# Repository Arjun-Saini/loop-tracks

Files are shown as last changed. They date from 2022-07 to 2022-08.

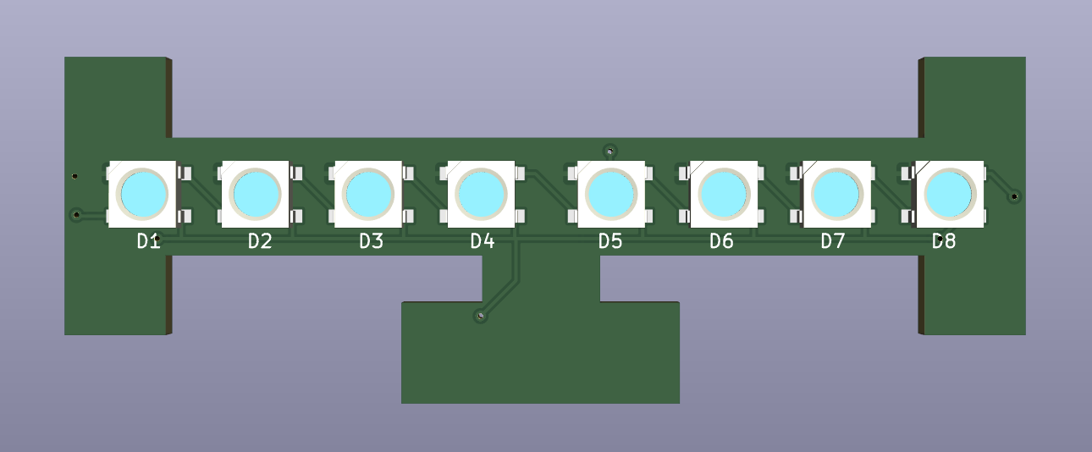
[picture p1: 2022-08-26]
images and diagrams/offshoot right.png

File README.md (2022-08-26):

# loop-tracks

This is the main repository for the loop-tracks project.
The server and UI for this project can be found at [loop-tracks-server](https://github.com/cogsandsquigs/loop-tracks-server) and [loop-tracks-ui](https://github.com/cogsandsquigs/loop-tracks-ui). Full documentation and other information for the project located [here](https://arjun-saini.notion.site/arjun-saini/Loop-Tracks-0d7150e50bd84f2c9db64b674ca986d8).

## images and diagrams

Images and diagrams used in the notion page.

## PCB Design

PCB project files for each track component, designed with [KiCad 6](https://www.kicad.org/).

## master

Master I2C device, code written for a [Particle Argon](https://docs.particle.io/argon/) using DeviceOS 5.0.0.

## slave

Slave I2C devices, code written for an [ATmega328p](https://www.microchip.com/en-us/product/ATmega328).

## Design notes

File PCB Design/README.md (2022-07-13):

# loop-tracks PCB designs
These are the PCB designs for the loop-tracks project

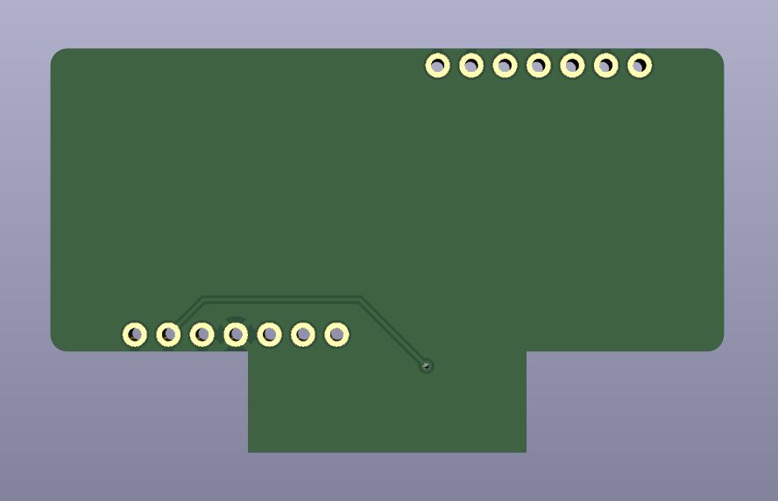
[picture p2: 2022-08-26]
images and diagrams/14-seg display.png

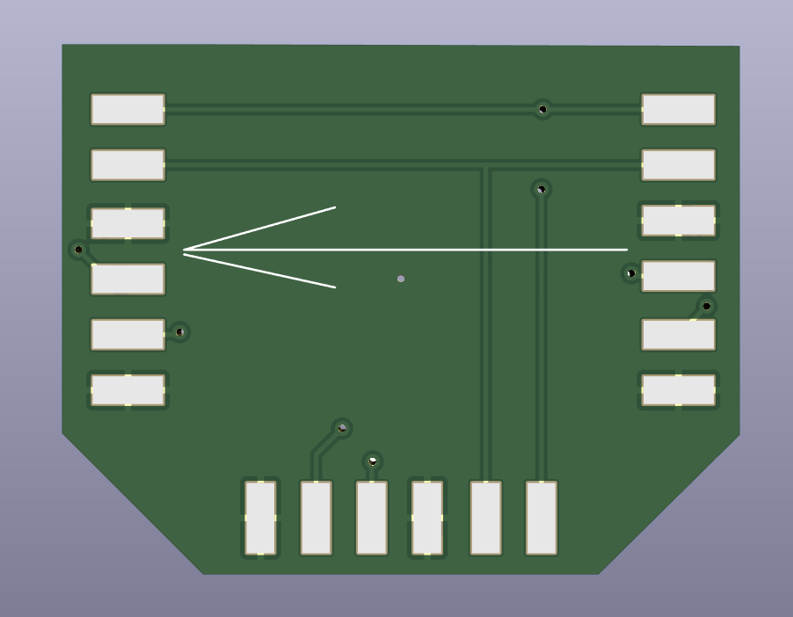
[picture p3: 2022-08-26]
images and diagrams/straight right arrows.png

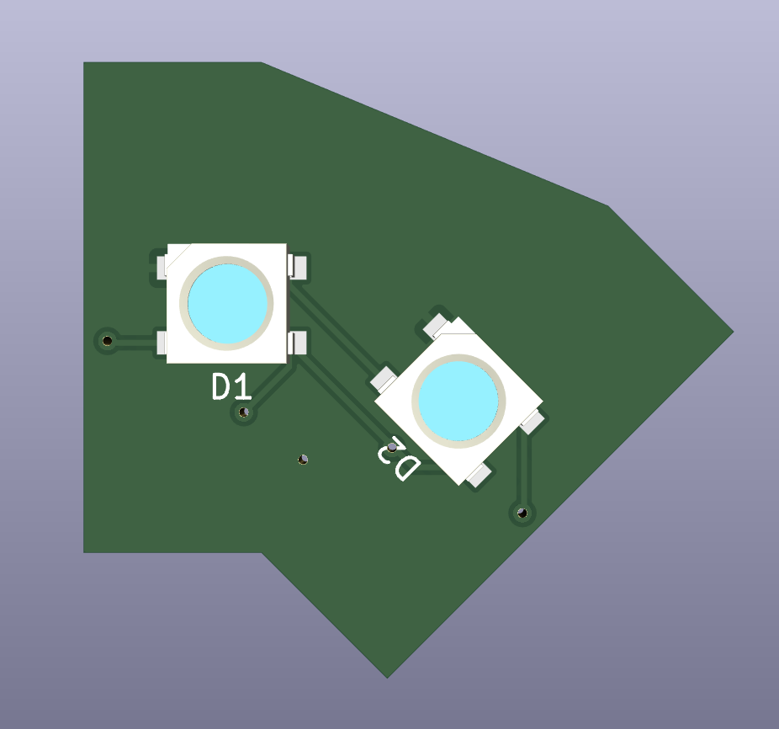
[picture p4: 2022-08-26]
images and diagrams/45 right.png

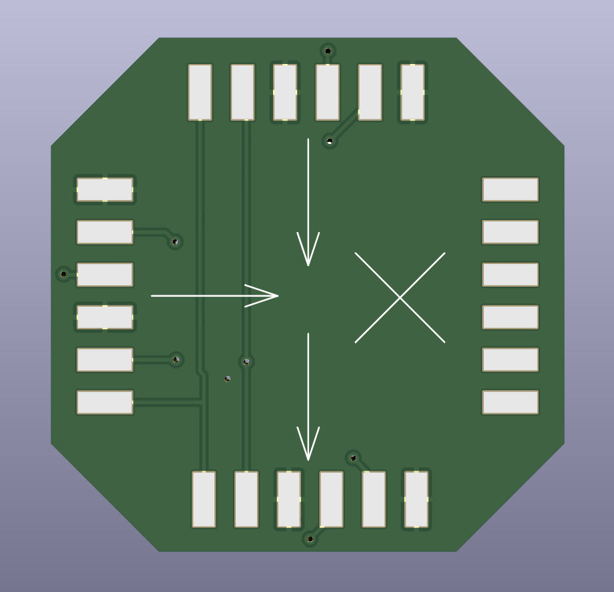
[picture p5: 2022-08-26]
images and diagrams/blocked intersection arrows.png

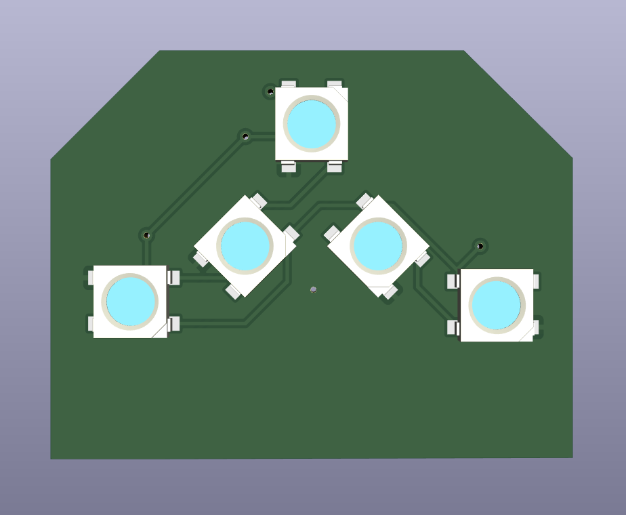
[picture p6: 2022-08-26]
images and diagrams/T-intersection.png

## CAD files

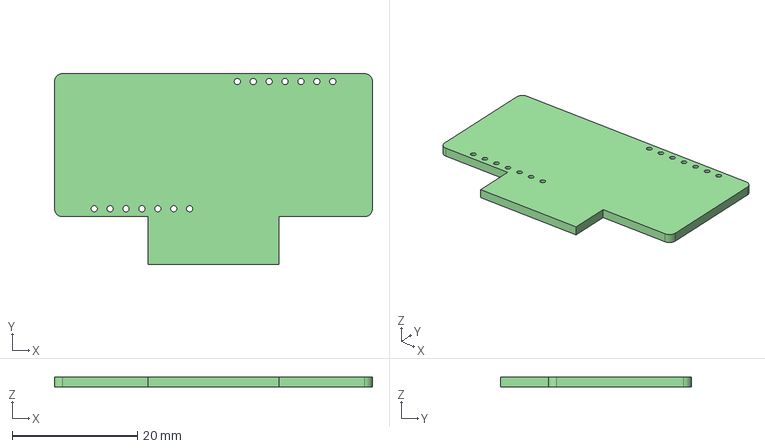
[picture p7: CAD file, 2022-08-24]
PCB Design/3d models/14 segment display.STEP
50.8 x 30.5 x 1.60 mm

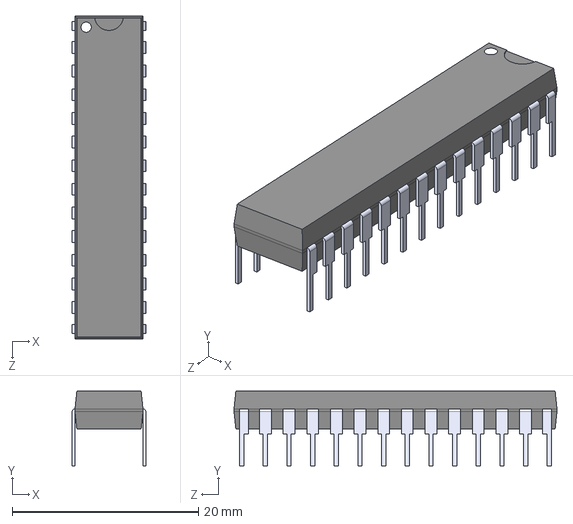
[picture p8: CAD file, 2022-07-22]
PCB Design/microcontroller_th/ATMEGA328P-PU/ATMEGA328P-PU.step
7.90 x 8.00 x 34.7 mm

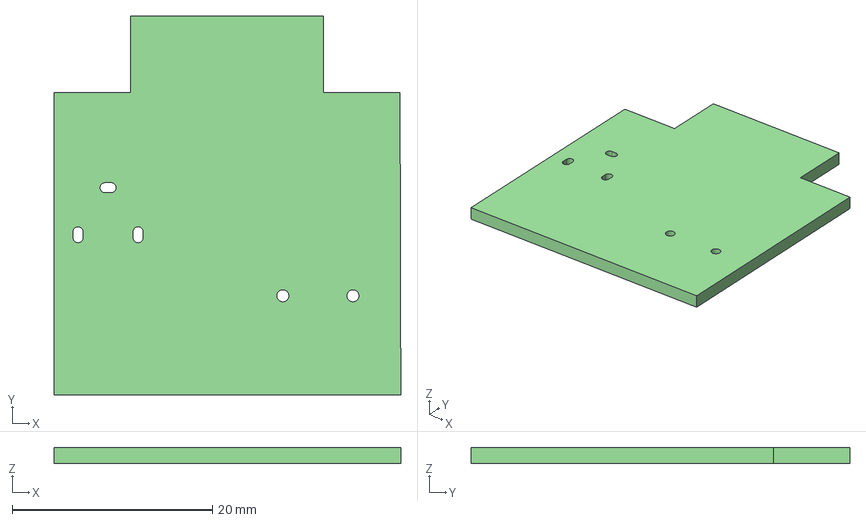
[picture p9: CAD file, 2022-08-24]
PCB Design/3d models/power mount.STEP
34.6 x 37.8 x 1.60 mm

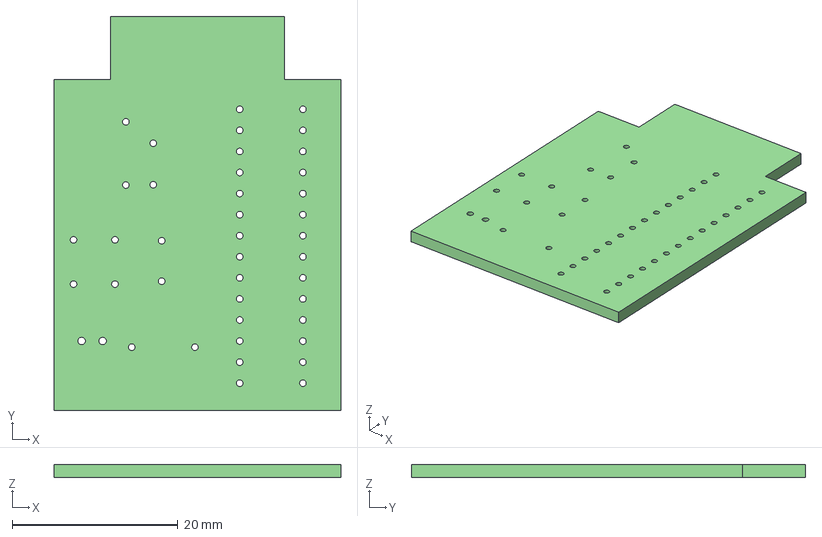
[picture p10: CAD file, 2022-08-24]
PCB Design/3d models/microcontroller mount.STEP
34.5 x 47.5 x 1.60 mm

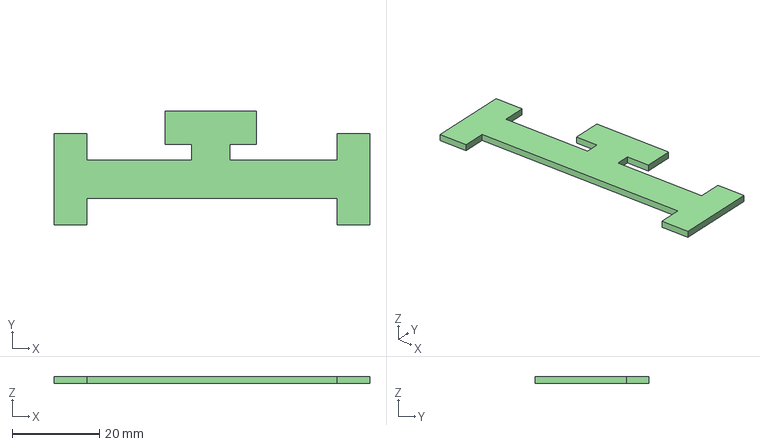
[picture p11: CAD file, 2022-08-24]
PCB Design/3d models/straight stick offshoot.STEP
72.5 x 26.1 x 1.60 mm

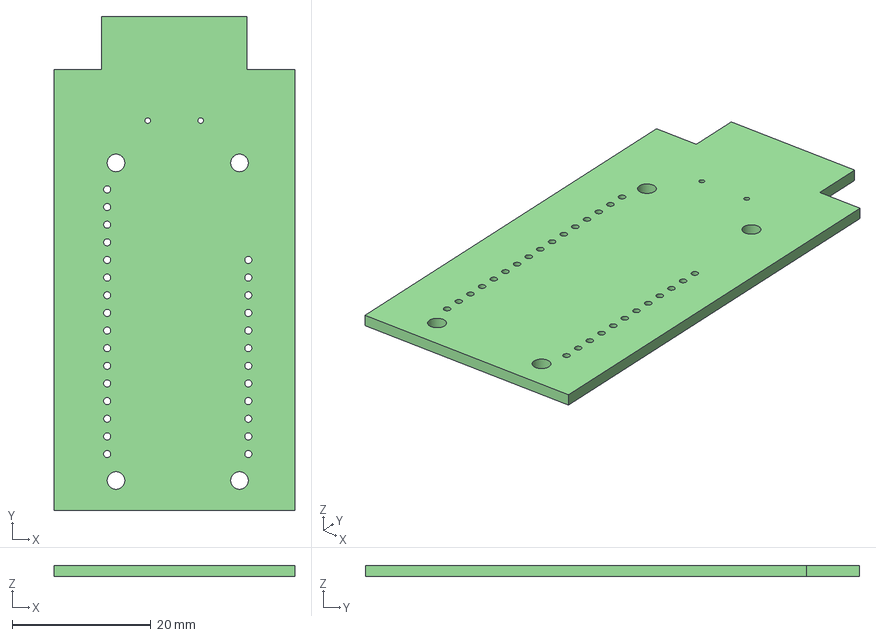
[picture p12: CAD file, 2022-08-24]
PCB Design/3d models/argon mount.STEP
34.6 x 71.1 x 1.60 mm

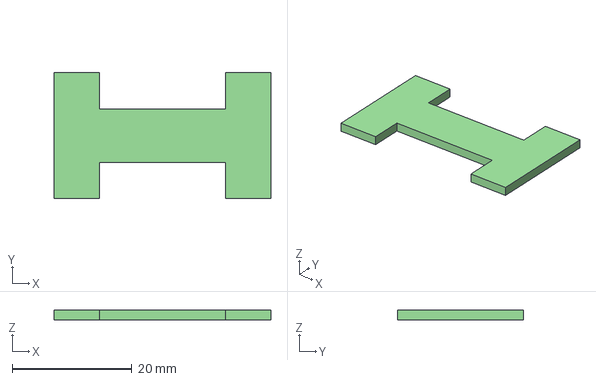
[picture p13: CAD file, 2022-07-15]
PCB Design/3d models/straight stick half size.STEP
36.2 x 21.0 x 1.60 mm

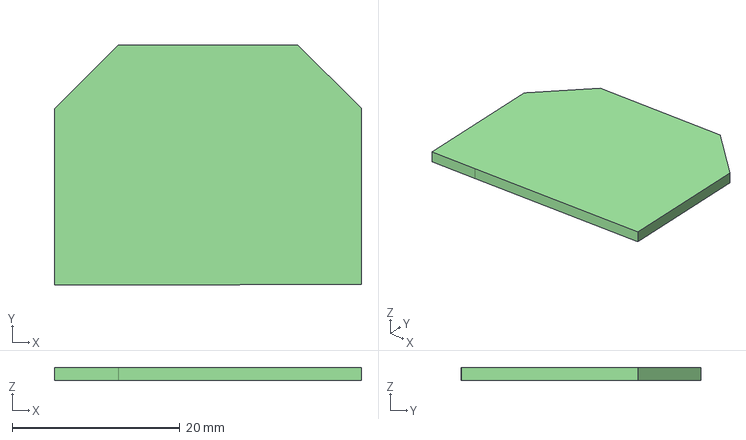
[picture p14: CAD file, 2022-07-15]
PCB Design/3d models/T straight right.STEP
36.6 x 28.6 x 1.60 mm

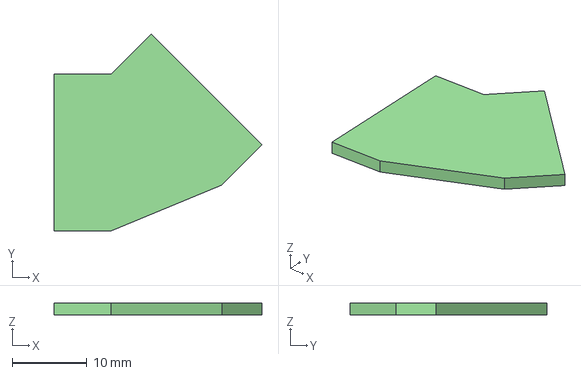
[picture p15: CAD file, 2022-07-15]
PCB Design/3d models/45 degree left.STEP
27.9 x 26.4 x 1.60 mm

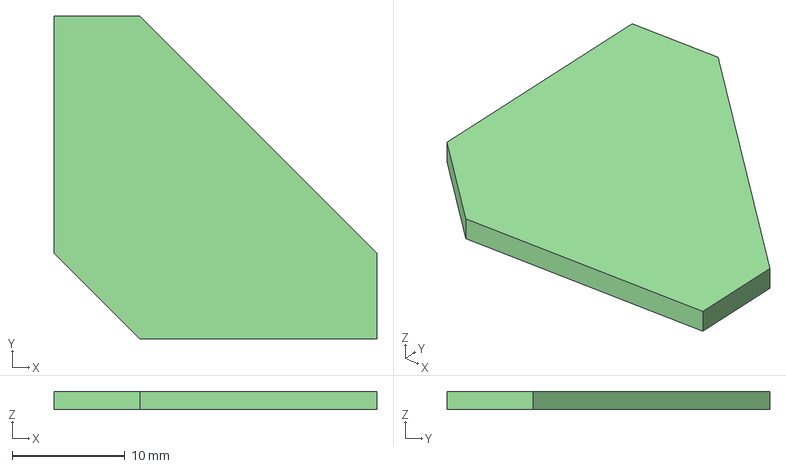
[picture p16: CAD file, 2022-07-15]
PCB Design/3d models/90 degree right.STEP
28.6 x 28.6 x 1.60 mm

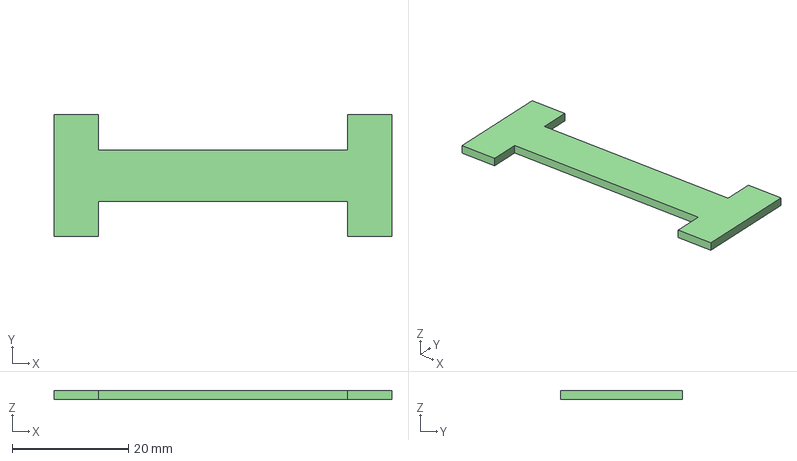
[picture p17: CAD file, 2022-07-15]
PCB Design/3d models/straight stick.STEP
58.2 x 21.0 x 1.60 mm

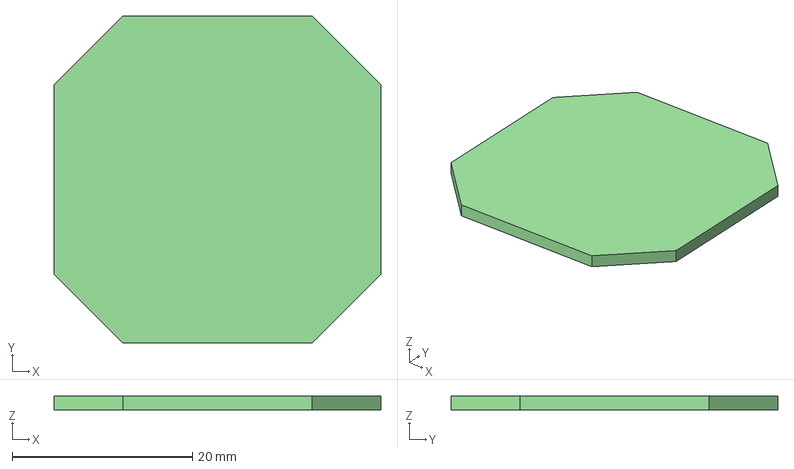
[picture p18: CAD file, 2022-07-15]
PCB Design/3d models/intersection.STEP
36.2 x 36.2 x 1.60 mm

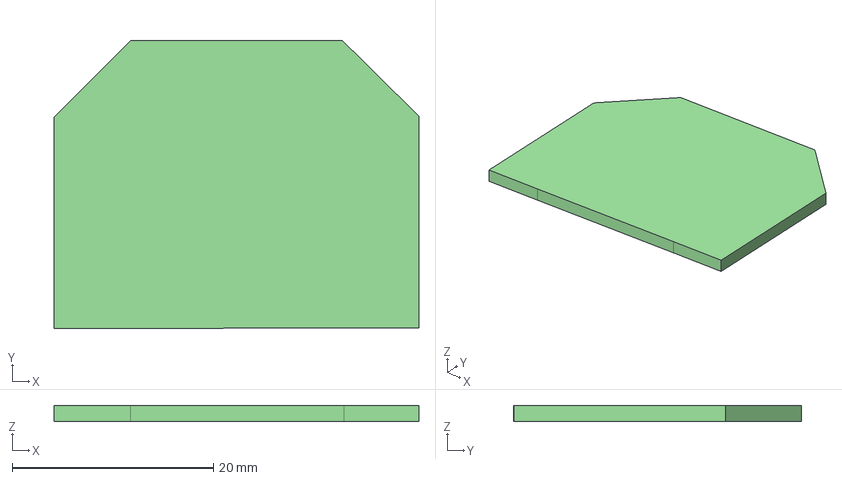
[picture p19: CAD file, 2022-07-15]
PCB Design/3d models/T turn from left.STEP
36.2 x 28.6 x 1.60 mm

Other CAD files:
PCB Design/3d models/T straight left.STEP
PCB Design/3d models/45 degree right.STEP
PCB Design/3d models/90 degree left.STEP
PCB Design/3d models/T turn from right.STEP

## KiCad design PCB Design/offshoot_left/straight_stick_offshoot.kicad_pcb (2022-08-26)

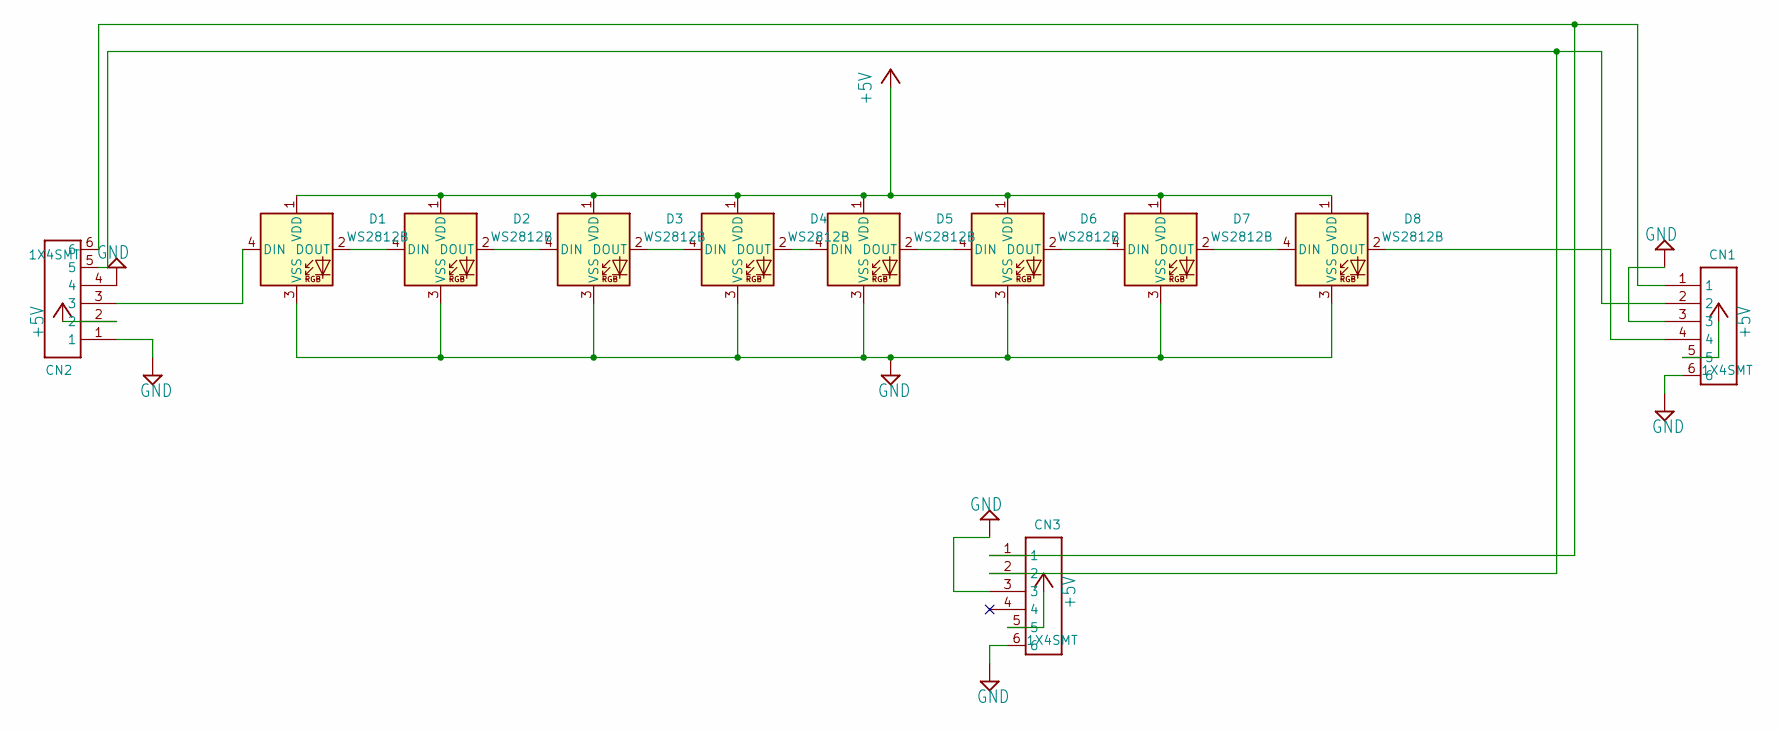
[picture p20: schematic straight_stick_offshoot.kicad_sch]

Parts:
CN1, CN2, CN3: 1X4SMT; 1X4-SMT
D1, D2, D3, D4, D5, D6, D7, D8: WS2812B; LED_WS2812B_PLCC4_5.0x5.0mm_P3.2mm

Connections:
+5V: CN1.5, CN2.2, CN3.5, D1.1 (VDD), D2.1 (VDD), D3.1 (VDD), D4.1 (VDD), D5.1 (VDD), D6.1 (VDD), D7.1 (VDD), D8.1 (VDD)
GND: CN1.3, CN1.6, CN2.1, CN2.4, CN3.3, CN3.6, D1.3 (VSS), D2.3 (VSS), D3.3 (VSS), D4.3 (VSS), D5.3 (VSS), D6.3 (VSS), D7.3 (VSS), D8.3 (VSS)
unnamed: CN1.1, CN2.6, CN3.1
unnamed: CN1.2, CN2.5, CN3.2
unnamed: CN1.4, D8.2 (DOUT)
unnamed: CN2.3, D1.4 (DIN)
unnamed: D1.2 (DOUT), D2.4 (DIN)
unnamed: D2.2 (DOUT), D3.4 (DIN)
unnamed: D3.2 (DOUT), D4.4 (DIN)
unnamed: D4.2 (DOUT), D5.4 (DIN)
unnamed: D5.2 (DOUT), D6.4 (DIN)
unnamed: D6.2 (DOUT), D7.4 (DIN)
unnamed: D7.2 (DOUT), D8.4 (DIN)

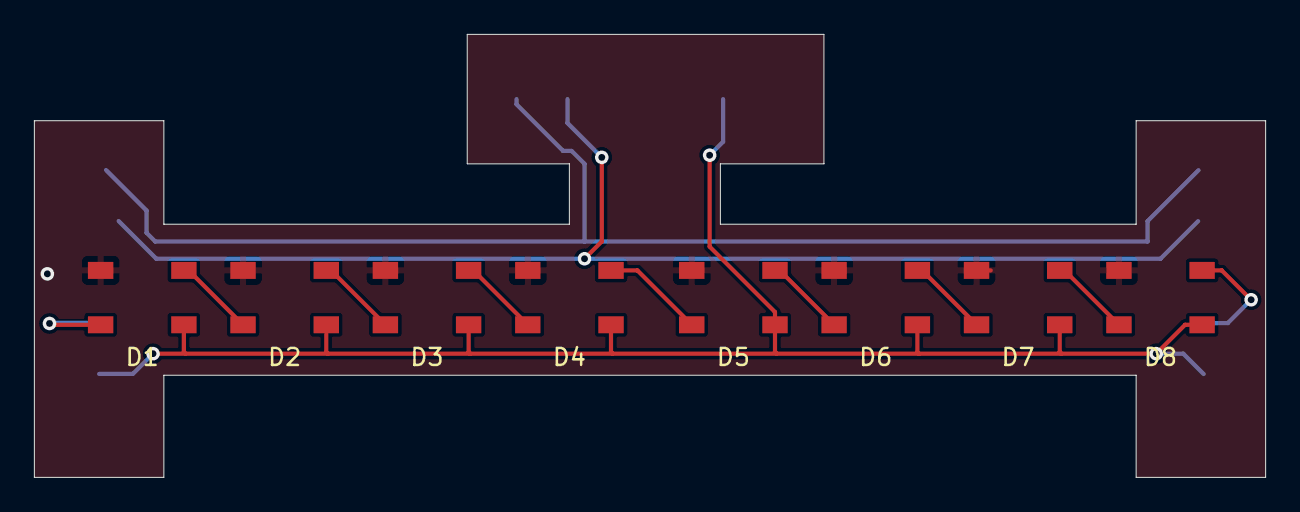
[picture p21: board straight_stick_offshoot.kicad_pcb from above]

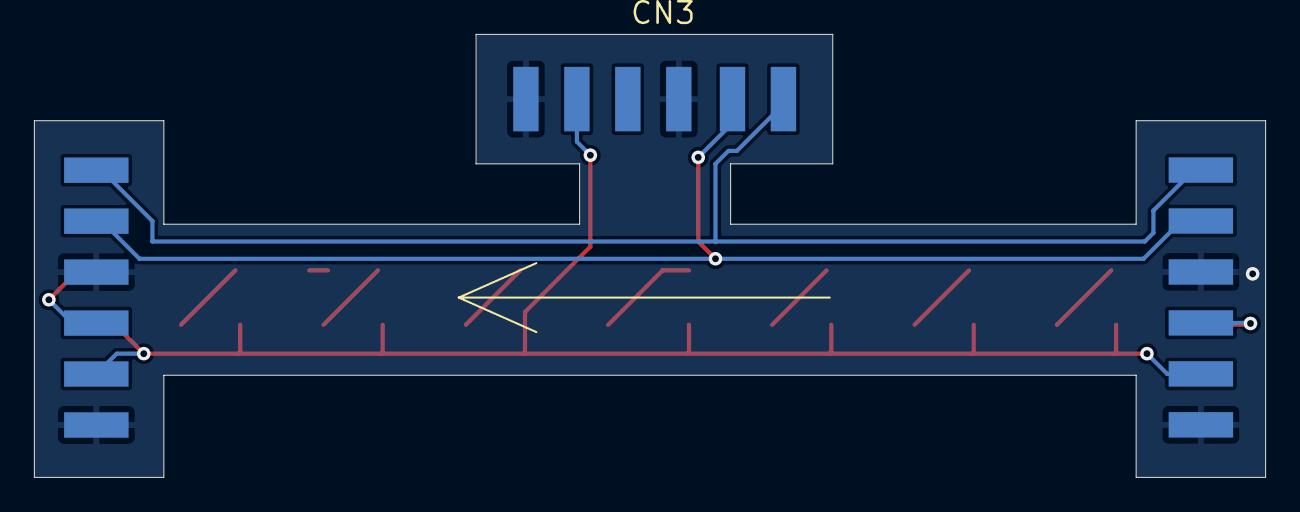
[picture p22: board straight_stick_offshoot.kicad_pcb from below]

Board: 2 copper layers, 72.5 x 26.1 mm, 11 parts (3 on the bottom side), 13 nets.

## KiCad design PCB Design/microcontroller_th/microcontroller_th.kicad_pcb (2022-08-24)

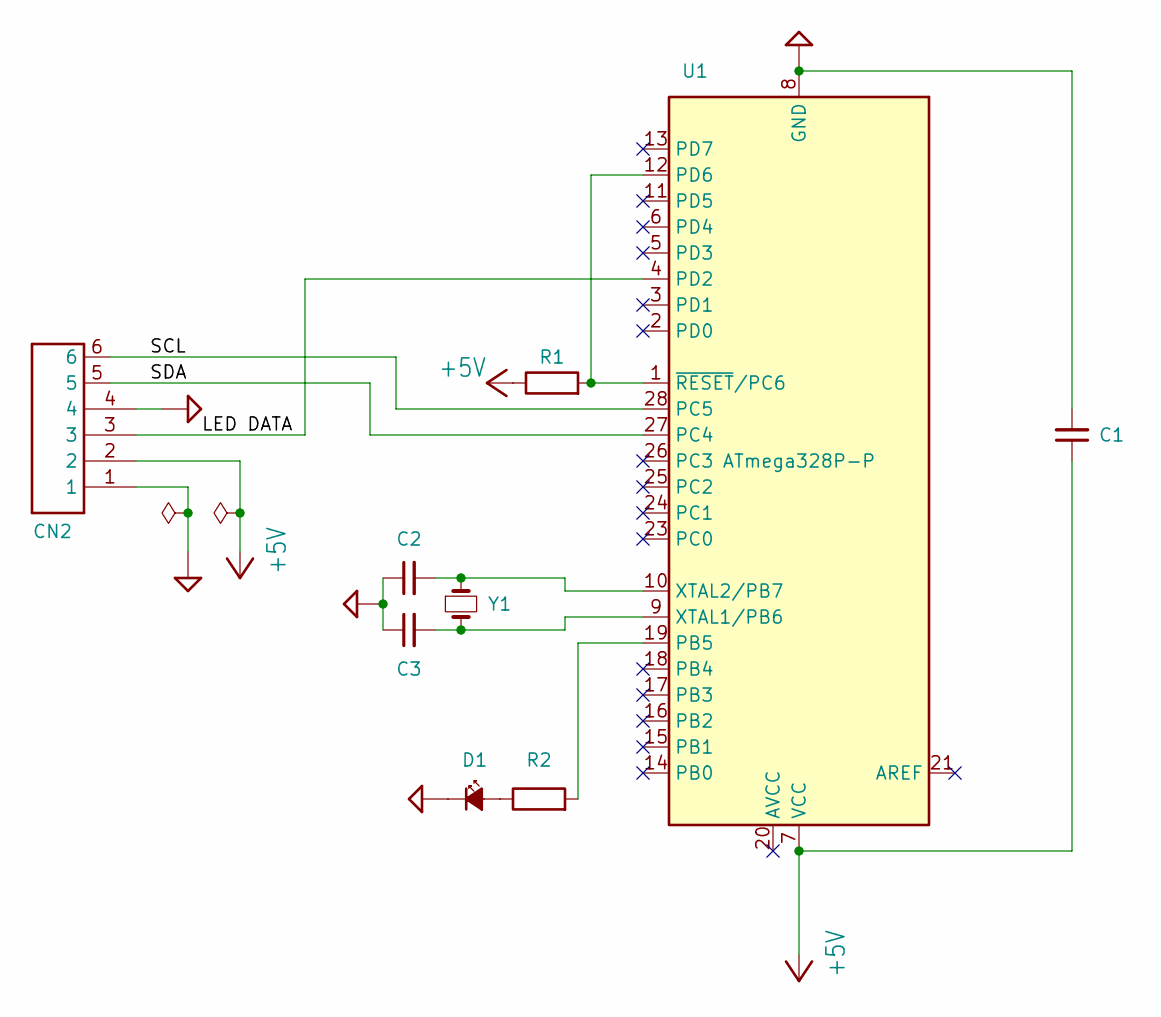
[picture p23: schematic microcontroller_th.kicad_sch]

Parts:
C1, C2, C3: C_Small; C_Disc_D4.7mm_W2.5mm_P5.00mm
CN2: 1X4SMT; 1X4-SMT
D1: LED_Small_Filled; LED_D3.0mm
R1, R2: R; R_Axial_DIN0207_L6.3mm_D2.5mm_P7.62mm_Horizontal
U1: ATmega328P-P; DIP-28_W7.62mm
Y1: Crystal_Small; Crystal_HC49-U_Vertical

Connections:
+5V: C1.1, CN2.2, R1.1, U1.7 (VCC)
/LED DATA: CN2.3, U1.4 (PD2)
/SCL: CN2.6, U1.28 (PC5)
/SDA: CN2.5, U1.27 (PC4)
GND: C1.2, C2.1, C3.1, CN2.1, CN2.4, D1.1 (K), U1.8 (GND), U1.22 (GND)
unnamed: C2.2, U1.10 (XTAL2/PB7), Y1.1
unnamed: C3.2, U1.9 (XTAL1/PB6), Y1.2
unnamed: D1.2 (A), R2.1
unnamed: R2.2, U1.19 (PB5)
unnamed: R1.2, U1.1 (~RESET/PC6), U1.12 (PD6)

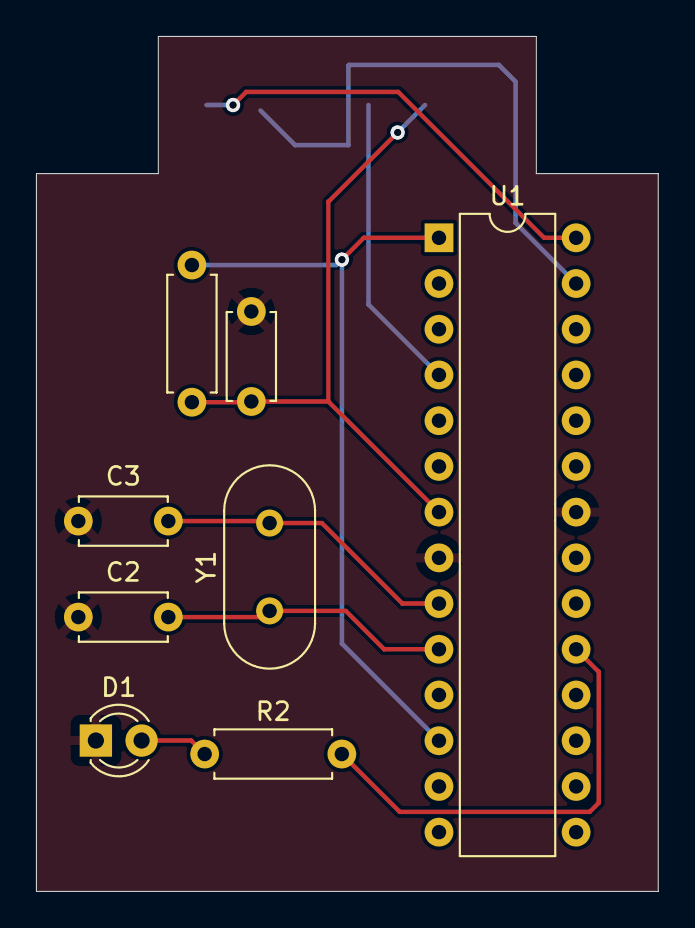
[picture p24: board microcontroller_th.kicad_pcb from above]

Board: 2 copper layers, 34.5 x 47.5 mm, 9 parts (1 on the bottom side), 10 nets.

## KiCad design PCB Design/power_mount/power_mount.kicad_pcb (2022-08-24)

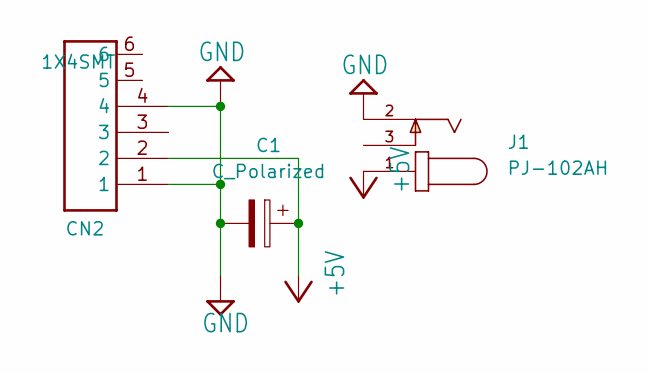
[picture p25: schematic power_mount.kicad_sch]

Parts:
C1: C_Polarized; CP_Radial_D12.5mm_P6.00mm
CN2: 1X4SMT; 1X4-SMT
J1: PJ-102AH

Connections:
+5V: C1.1, CN2.2, J1.1
GND: C1.2, CN2.1, CN2.4, J1.2

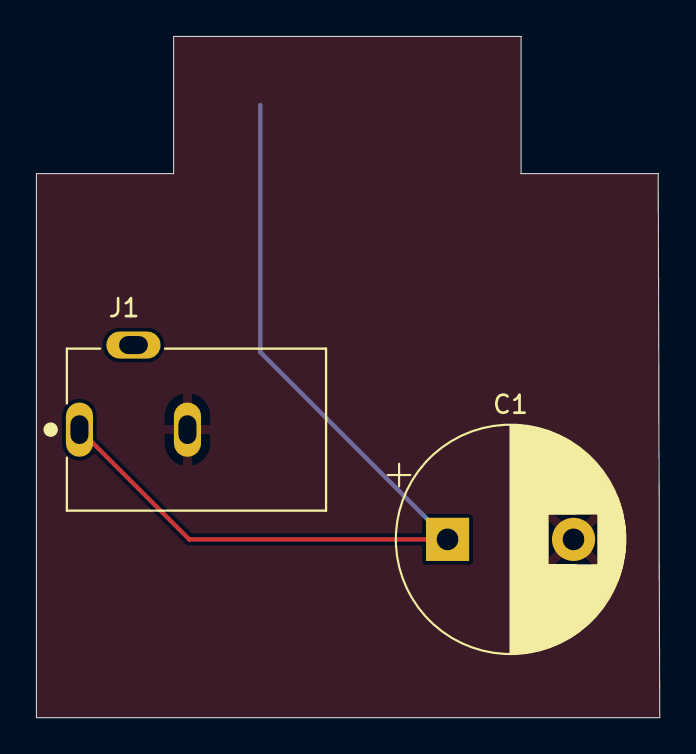
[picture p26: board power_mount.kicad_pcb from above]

Board: 2 copper layers, 34.6 x 37.8 mm, 3 parts (1 on the bottom side), 2 nets.

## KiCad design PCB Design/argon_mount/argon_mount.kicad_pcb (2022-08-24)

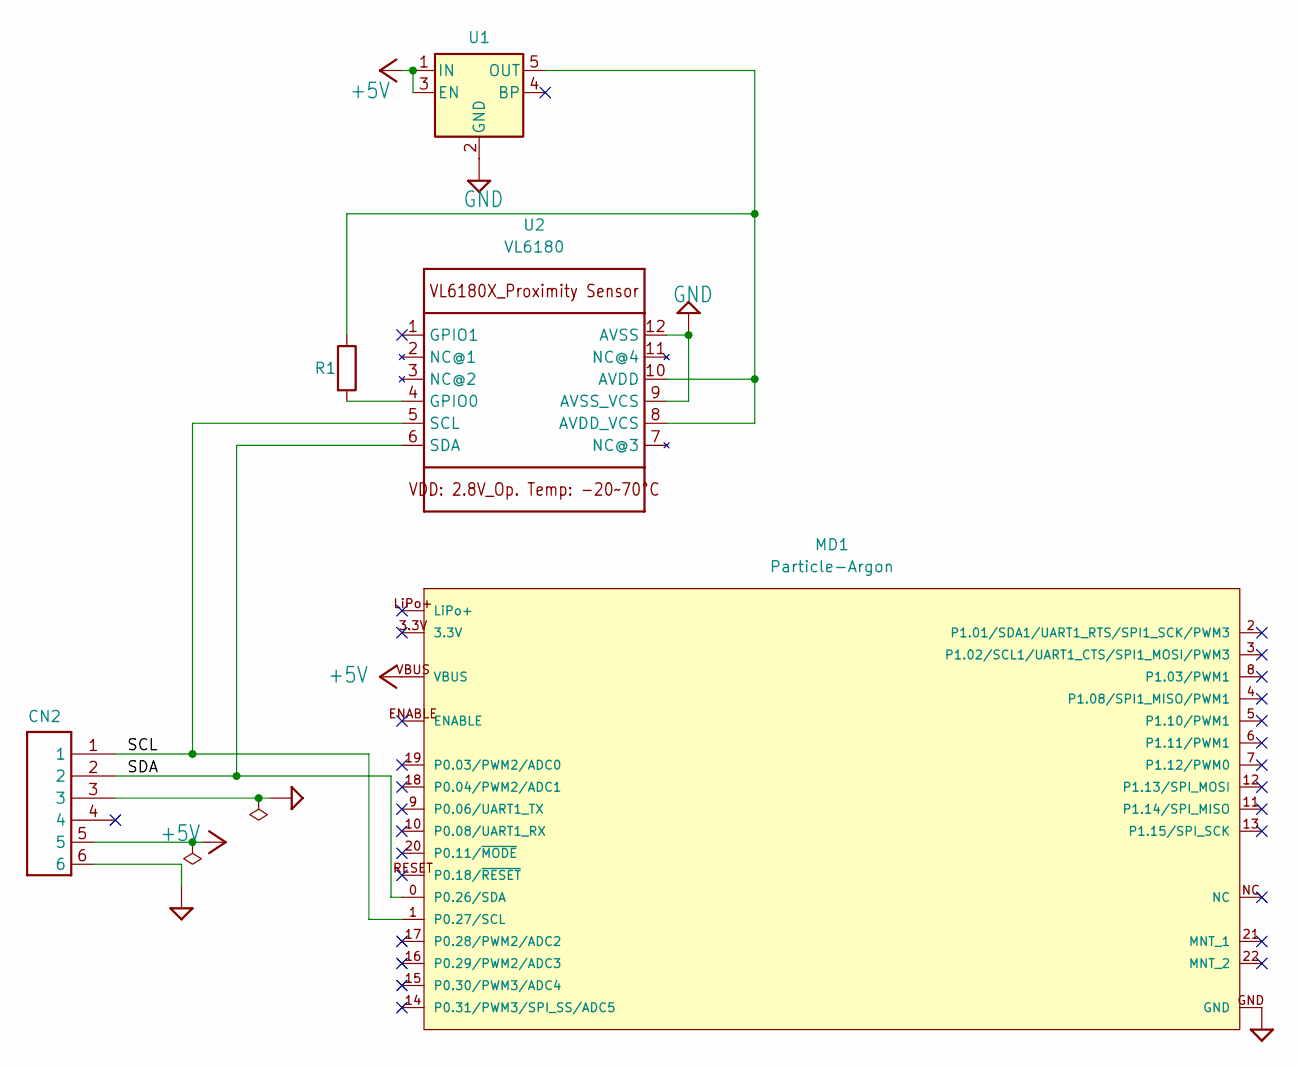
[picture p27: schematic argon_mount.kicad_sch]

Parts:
CN2: 1X4SMT; 1X4-SMT
MD1: Particle-Argon; Particle-Argon-0-0-MD1; manufacturer Particle; digikey description Bluetooth, WiFi 802.11b/g/n, Bluetooth 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
R1: R; R_Axial_DIN0207_L6.3mm_D2.5mm_P7.62mm_Horizontal
U1: MIC5219-2.85YM5; SOT-23-5
U2: VL6180

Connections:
+5V: CN2.5, MD1.VBUS, U1.1 (IN), U1.3 (EN)
/SCL: CN2.1, MD1.1 (P0.27/SCL), U2.5 (SCL)
/SDA: CN2.2, MD1.0 (P0.26/SDA), U2.6 (SDA)
GND: CN2.3, CN2.6, MD1.GND, U1.2 (GND), U2.9 (AVSS_VCS), U2.12 (AVSS)
unnamed: R1.1, U1.5 (OUT), U2.8 (AVDD_VCS), U2.10 (AVDD)
unnamed: R1.2, U2.4 (GPIO0)

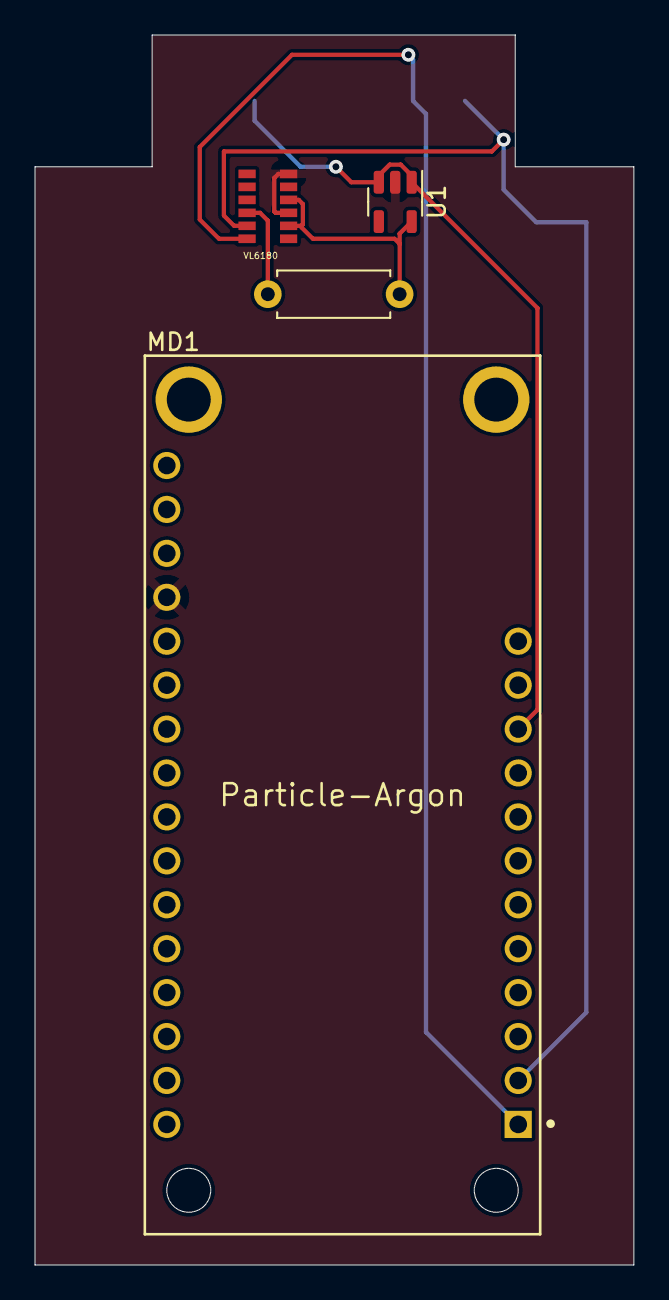
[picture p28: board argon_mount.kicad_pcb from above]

Board: 2 copper layers, 34.6 x 71.1 mm, 5 parts (1 on the bottom side), 6 nets.

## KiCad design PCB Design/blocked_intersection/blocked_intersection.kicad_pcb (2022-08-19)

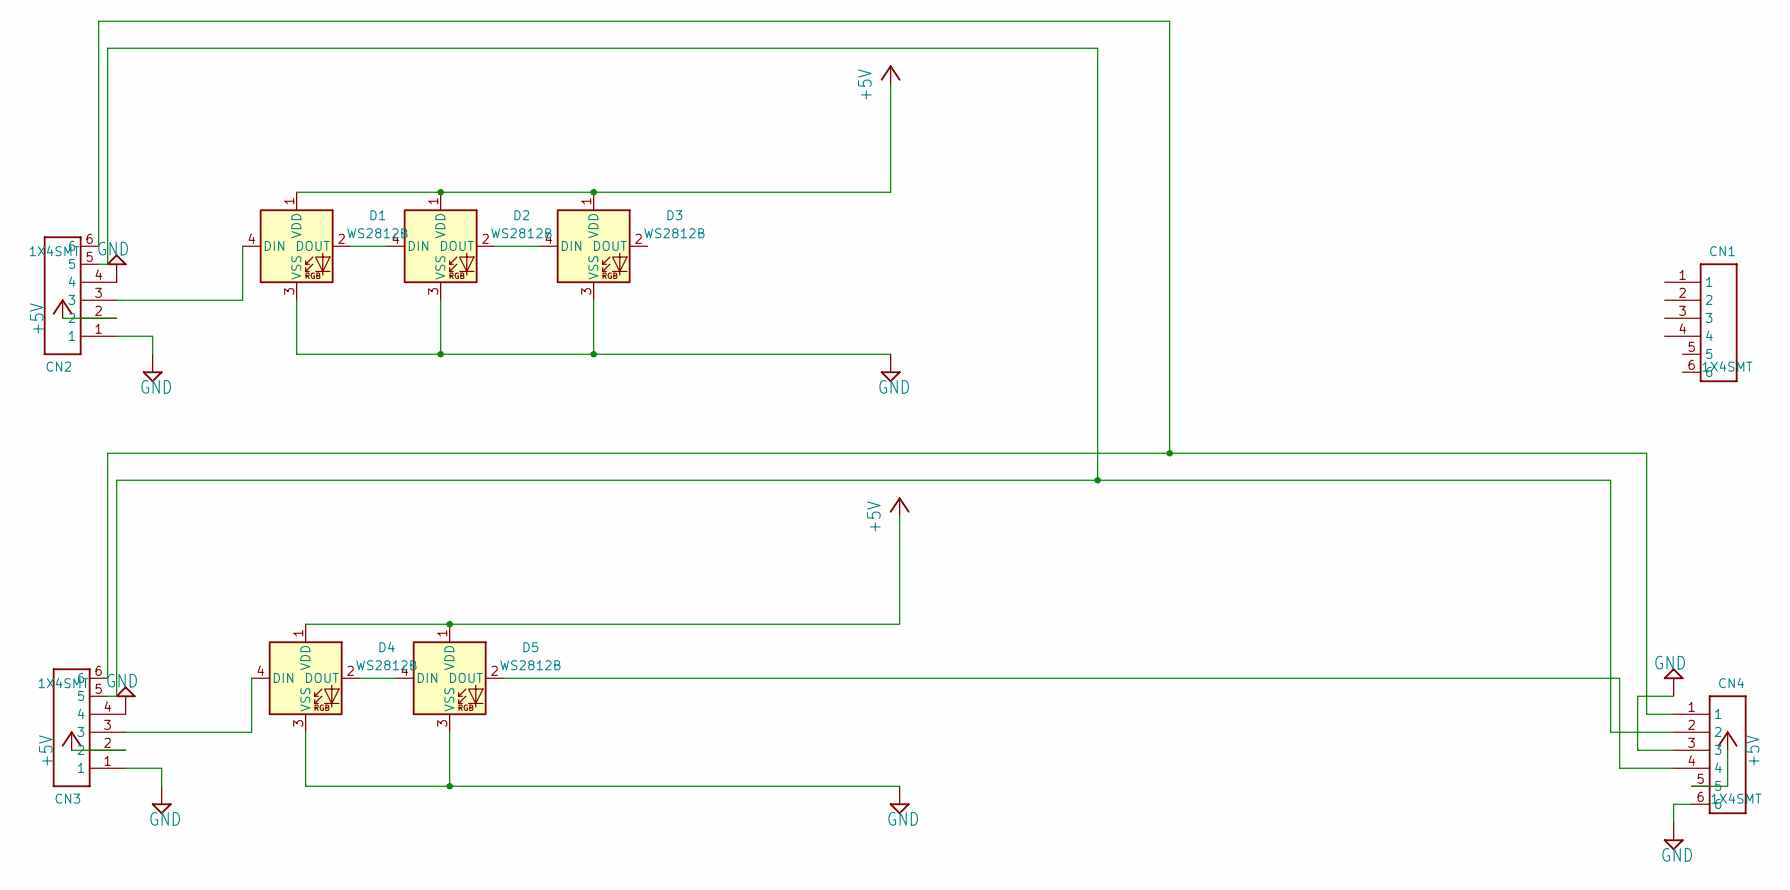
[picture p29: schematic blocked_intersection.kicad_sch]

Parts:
CN1, CN2, CN3, CN4: 1X4SMT; 1X4-SMT
D1, D2, D3, D4, D5: WS2812B; LED_WS2812B_PLCC4_5.0x5.0mm_P3.2mm

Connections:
+5V: CN2.2, CN3.2, CN4.5, D1.1 (VDD), D2.1 (VDD), D3.1 (VDD), D4.1 (VDD), D5.1 (VDD)
GND: CN2.1, CN2.4, CN3.1, CN3.4, CN4.3, CN4.6, D1.3 (VSS), D2.3 (VSS), D3.3 (VSS), D4.3 (VSS), D5.3 (VSS)
unnamed: CN2.3, D1.4 (DIN)
unnamed: CN2.5, CN3.5, CN4.2
unnamed: CN2.6, CN3.6, CN4.1
unnamed: CN3.3, D4.4 (DIN)
unnamed: D1.2 (DOUT), D2.4 (DIN)
unnamed: D2.2 (DOUT), D3.4 (DIN)
unnamed: D4.2 (DOUT), D5.4 (DIN)
unnamed: CN4.4, D5.2 (DOUT)

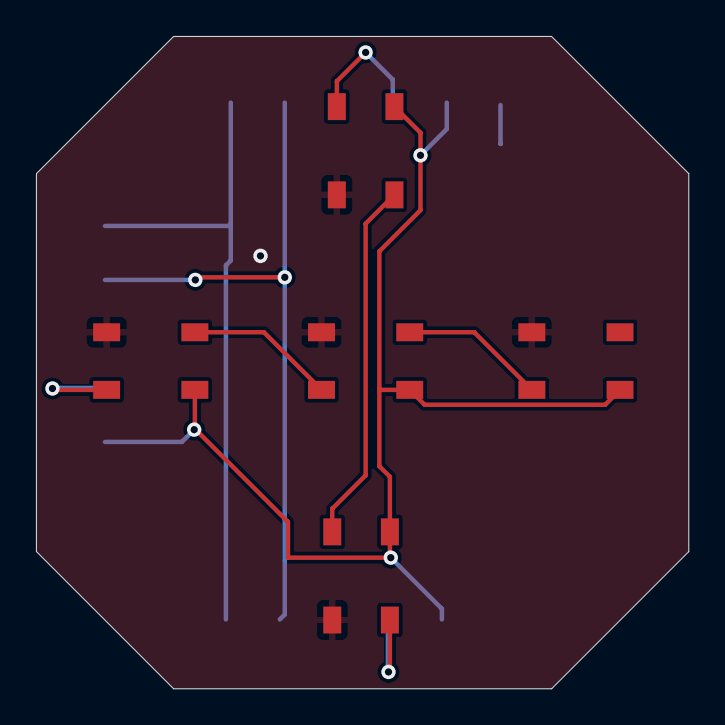
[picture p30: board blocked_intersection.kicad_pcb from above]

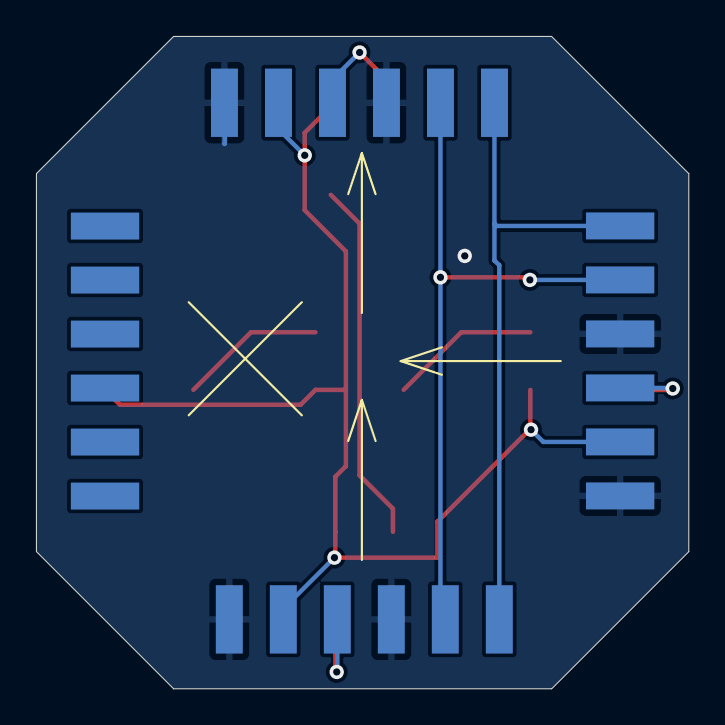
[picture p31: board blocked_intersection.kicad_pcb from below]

Board: 2 copper layers, 36.2 x 36.2 mm, 9 parts (4 on the bottom side), 10 nets.

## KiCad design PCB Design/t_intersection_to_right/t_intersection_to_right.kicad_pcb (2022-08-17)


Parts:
CN1, CN2, CN3: 1X4SMT; 1X4-SMT
D1, D3, D4, D6, D7: WS2812B; LED_WS2812B_PLCC4_5.0x5.0mm_P3.2mm

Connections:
+5V: CN1.5, CN2.2, CN3.2, D1.1 (VDD), D3.3 (VSS), D4.1 (VDD), D6.3 (VSS), D7.3 (VSS)
GND: CN1.3, CN1.6, CN2.1, CN2.4, CN3.1, CN3.4, D1.3 (VSS), D3.1 (VDD), D4.3 (VSS), D6.1 (VDD), D7.1 (VDD)
unnamed: CN1.1, CN2.6, CN3.6
unnamed: CN1.2, CN2.5, CN3.5
unnamed: CN1.4, D7.2 (DOUT)
unnamed: CN2.3, D3.4 (DIN)
unnamed: CN3.3, D4.4 (DIN)
unnamed: D1.4 (DIN), D4.2 (DOUT)
unnamed: D3.2 (DOUT), D6.4 (DIN)
unnamed: D6.2 (DOUT), D7.4 (DIN)



Board: 2 copper layers, 36.6 x 28.6 mm, 8 parts (3 on the bottom side), 10 nets.

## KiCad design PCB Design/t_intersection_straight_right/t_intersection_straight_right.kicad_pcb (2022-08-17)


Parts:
CN1, CN2, CN3: 1X4SMT; 1X4-SMT
D1, D3, D4, D6, D7: WS2812B; LED_WS2812B_PLCC4_5.0x5.0mm_P3.2mm

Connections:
+5V: CN1.5, CN2.2, CN3.5, D1.3 (VSS), D3.3 (VSS), D4.1 (VDD), D6.3 (VSS), D7.3 (VSS)
GND: CN1.3, CN1.6, CN2.1, CN2.4, CN3.3, CN3.6, D1.1 (VDD), D3.1 (VDD), D4.3 (VSS), D6.1 (VDD), D7.1 (VDD)
unnamed: CN1.1, CN2.6, CN3.1
unnamed: CN1.2, CN2.5, CN3.2
unnamed: CN1.4, D7.2 (DOUT)
unnamed: CN2.3, D1.4 (DIN)
unnamed: D1.2 (DOUT), D3.4 (DIN)
unnamed: D3.2 (DOUT), D6.4 (DIN)
unnamed: CN3.4, D4.4 (DIN)
unnamed: D6.2 (DOUT), D7.4 (DIN)



Board: 2 copper layers, 36.6 x 28.6 mm, 8 parts (3 on the bottom side), 10 nets.

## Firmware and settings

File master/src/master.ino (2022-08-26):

SYSTEM_MODE(MANUAL);
SYSTEM_THREAD(ENABLED);

#include "HttpClient.h"
#include "JsonParserGeneratorRK.h"
#include "City.cpp"
#include "Adafruit_VL6180X.h"
#include "MQTT.h"
#include "Adafruit_GFX_RK.h"
#include "Adafruit_LEDBackpack_RK.h"
#include "twiboot.h"

#define UPDATE_INTERVAL 604800000 // milliseconds between program flashes
#define DEFAULT_SLAVE_ADR 0x29    // address that all slaves are set to when bootloader starts
#define PROXIMITY_THRESHOLD 100   // distance in mm that triggers lightshow

/**
 * @brief a train from the HTTP API and stores it in the railways array.
 * @param trainIndex The Index of train in the railway.
 * @param currentRailway The current railway we are on.
 * @return true if there are no more trains to parse, false otherwise.
 */
bool parseTrain(int trainIndex, Railway &currentRailway);

/**
 * @brief Sends the data to the slaves
 * @param railwayVectorIndex Railway index in the Railway vector
 * @param currentRailway The current railway being processed and sent
 */
void sendData(int railwayVectorIndex, Railway currentRailway);

// BLE callback
void onDataReceived(const uint8_t *data, size_t len, const BlePeerDevice &peer, void *context);

/**
 * @brief Sends rainbow command to every slave.
 * @param length Duration in ms for rainbow to last.
 */
void lightshow(int length);

// MQTT callback
void callback(char *topic, byte *payload, unsigned int length);

/**
 * @brief Displays 4 character string on 14 segment display
 * @param display target display
 * @param str 4 character string
 */
void alphaDisplay(Adafruit_AlphaNum4 display, String str);

/**
 * @brief Flashes program to designed i2c address 
 * @param _prog program hex array
 * @param _len size of hex array
 * @param _adr target address
 */
void flashProg(unsigned char *_prog, unsigned int _len, int _adr);

/**
 * @brief Thread that proximity sensor runs on
 * @param param 
 */
void proximityThread(void *param);

// use hexed.it to generate code snippet, upload arduino sketch hex file WITHOUT bootloader
unsigned char slaveCode[8626] = {
	// Offset 0x00000000 to 0x000021B1
	0x0C, 0x94, 0x68, 0x00, 0x0C, 0x94, 0x90, 0x00, 0x0C, 0x94, 0x90, 0x00,
	0x0C, 0x94, 0x90, 0x00, 0x0C, 0x94, 0x90, 0x00, 0x0C, 0x94, 0x90, 0x00,
	0x0C, 0x94, 0x90, 0x00, 0x0C, 0x94, 0x90, 0x00, 0x0C, 0x94, 0x90, 0x00,
	0x0C, 0x94, 0x90, 0x00, 0x0C, 0x94, 0x90, 0x00, 0x0C, 0x94, 0x90, 0x00,
	0x0C, 0x94, 0x90, 0x00, 0x0C, 0x94, 0x90, 0x00, 0x0C, 0x94, 0x90, 0x00,
	0x0C, 0x94, 0x90, 0x00, 0x0C, 0x94, 0x5F, 0x08, 0x0C, 0x94, 0x90, 0x00,
	0x0C, 0x94, 0x2D, 0x08, 0x0C, 0x94, 0x07, 0x08, 0x0C, 0x94, 0x90, 0x00,
	0x0C, 0x94, 0x90, 0x00, 0x0C, 0x94, 0x90, 0x00, 0x0C, 0x94, 0x90, 0x00,
	0x0C, 0x94, 0xA9, 0x08, 0x0C, 0x94, 0x90, 0x00, 0x00, 0x00, 0x00, 0x00,
	0x24, 0x00, 0x27, 0x00, 0x2A, 0x00, 0x00, 0x00, 0x00, 0x08, 0x00, 0x02,
	0x01, 0x00, 0x00, 0x03, 0x04, 0x07, 0x00, 0x00, 0x00, 0x00, 0x00, 0x00,
	0x00, 0x00, 0x72, 0x61, 0x6E, 0x64, 0x6F, 0x6D, 0x69, 0x7A, 0x65, 0x20,
	0x61, 0x64, 0x64, 0x72, 0x65, 0x73, 0x73, 0x3A, 0x20, 0x00, 0x01, 0x02,
	0x04, 0x08, 0x10, 0x20, 0x40, 0x80, 0x01, 0x02, 0x04, 0x08, 0x10, 0x20,
	0x01, 0x02, 0x04, 0x08, 0x10, 0x20, 0x00, 0x00, 0x00, 0x00, 0x25, 0x00,
	0x28, 0x00, 0x2B, 0x00, 0x04, 0x04, 0x04, 0x04, 0x04, 0x04, 0x04, 0x04,
	0x02, 0x02, 0x02, 0x02, 0x02, 0x02, 0x03, 0x03, 0x03, 0x03, 0x03, 0x03,
	0xC3, 0x09, 0xF5, 0x0C, 0x11, 0x24, 0x1F, 0xBE, 0xCF, 0xEF, 0xD8, 0xE0,
	0xDE, 0xBF, 0xCD, 0xBF, 0x11, 0xE0, 0xA0, 0xE0, 0xB1, 0xE0, 0xE6, 0xE6,
	0xF1, 0xE2, 0x02, 0xC0, 0x05, 0x90, 0x0D, 0x92, 0xAC, 0x34, 0xB1, 0x07,
	0xD9, 0xF7, 0x26, 0xE0, 0xAC, 0xE4, 0xB1, 0xE0, 0x01, 0xC0, 0x1D, 0x92,
	0xAE, 0x35, 0xB2, 0x07, 0xE1, 0xF7, 0x10, 0xE0, 0xC7, 0xE6, 0xD0, 0xE0,
	0x04, 0xC0, 0x21, 0x97, 0xFE, 0x01, 0x0E, 0x94, 0x74, 0x0F, 0xC6, 0x36,
	0xD1, 0x07, 0xC9, 0xF7, 0x0E, 0x94, 0x7E, 0x0A, 0x0C, 0x94, 0xA6, 0x10,
	0x0C, 0x94, 0x00, 0x00, 0x1F, 0x93, 0xCF, 0x93, 0xDF, 0x93, 0x11, 0xE0,
	0x18, 0x0F, 0x20, 0x91, 0x4A, 0x06, 0x12, 0x17, 0xA1, 0xF1, 0xC0, 0x91,
	0x4B, 0x06, 0xD0, 0x91, 0x4C, 0x06, 0x21, 0x50, 0x70, 0xE0, 0x60, 0xE0,
	0x61, 0xF0, 0x8F, 0x3F, 0xF1, 0xF4, 0x30, 0xE0, 0x50, 0xE0, 0x40, 0xE0,
	0x6F, 0xEF, 0x7F, 0xEF, 0x80, 0xE0, 0x90, 0xE0, 0x0E, 0x94, 0xE8, 0x0E,
	0xB9, 0x01, 0xFE, 0x01, 0x40, 0x91, 0x46, 0x06, 0x50, 0x91, 0x47, 0x06,
	0xCF, 0x01, 0x8C, 0x1B, 0x9D, 0x0B, 0x84, 0x17, 0x95, 0x07, 0x98, 0xF4,
	0x40, 0x81, 0x46, 0x9F, 0xC0, 0x01, 0x47, 0x9F, 0x90, 0x0D, 0x11, 0x24,
	0x90, 0x83, 0x31, 0x96, 0xED, 0xCF, 0x81, 0x2F, 0x90, 0xE0, 0x98, 0x2F,
	0x88, 0x27, 0x01, 0x97, 0x62, 0x2F, 0x70, 0xE0, 0x0E, 0x94, 0x60, 0x0F,
	0xE2, 0xCF, 0x10, 0x93, 0x4A, 0x06, 0xDF, 0x91, 0xCF, 0x91, 0x1F, 0x91,
	0x08, 0x95, 0x8F, 0x92, 0x9F, 0x92, 0xAF, 0x92, 0xBF, 0x92, 0xCF, 0x92,
	0xDF, 0x92, 0xEF, 0x92, 0xFF, 0x92, 0xCF, 0x93, 0x20, 0x91, 0x44, 0x06,
	0x30, 0x91, 0x45, 0x06, 0x82, 0x17, 0x93, 0x07, 0xE8, 0xF5, 0x4B, 0x01,
	0xAA, 0x24, 0xBB, 0x24, 0xC8, 0x2D, 0xC5, 0x2E, 0xD6, 0x2E, 0xE7, 0x2E,
	0xFF, 0x24, 0xBC, 0x2D, 0xA4, 0x2F, 0x20, 0x91, 0x4A, 0x06, 0x22, 0x23,
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
};

/*
all loop segment sizes must be the same
brown line receives all loop data for cta
no output segment can be 1, 12, or 24 pixels long, causes conflict with slave protocol
*/

// Chinatown to North/Clybourn
Railway redLineCTA = Railway(
    // checkpoints in order starting at slave position, should be a checkpoint at each bend/turn, no 3 adjacent checkpoints can form an angle smaller than 90 degrees
    {Checkpoint(41.853028, -87.63109), Checkpoint(41.9041, -87.628921), Checkpoint(41.903888, -87.639506), Checkpoint(41.913732, -87.652380), Checkpoint(41.9253, -87.65286)},
    {25, 3, 7, 5}, // pixels in between each checkpoint, should have 1 less element than checkpoint vector
    {0, 40, 0, 0}, // size of each output segment: before loop, after loop, in loop, in green
    "red",
    {"ff0000", "0a0000"}, // hex color values for head and body/tail of the train
    {0, 0, 0, 0}          // checkpoint bounds for lower loop, upper loop, lower green, upper green, these are only used for merging different rail colors onto one track
);

// Pulaski to Western (O'Hare branch)
Railway blueLineCTA = Railway(
    {Checkpoint(41.873647, -87.727931), Checkpoint(41.875666, -87.672961), Checkpoint(41.875293, -87.640976), Checkpoint(41.875660, -87.627620), Checkpoint(41.885738, -87.629540), Checkpoint(41.885698, -87.639828), Checkpoint(41.915497, -87.686258)},
    {12, 8, 5, 5, 5, 25},
    {0, 60, 0, 0},
    "blue",
    {"0000ff", "00000a"},
    {0, 0, 0, 0});

// Sedgewick to Loop
Railway brownLineCTA = Railway(
    {Checkpoint(41.9107586, -87.648068), Checkpoint(41.9103656, -87.6373962), Checkpoint(41.885840, -87.633990), Checkpoint(41.8770372, -87.6342823), Checkpoint(41.8767992, -87.6255196), Checkpoint(41.885921, -87.626137), Checkpoint(41.885840, -87.633990)},
    {5, 15, 10, 10, 10, 10},
    {20, 0, 40, 0},
    "brown",
    {"ffff00", "0a0a00"},
    {2, 6, 0, 0});

// Cermak-McCormick to Kedzie
Railway greenLineCTA = Railway(
    {Checkpoint(41.853115, -87.626402), Checkpoint(41.876946, -87.626046), Checkpoint(41.885921, -87.626137), Checkpoint(41.885724, -87.633945), Checkpoint(41.88422, -87.696234)},
    {15, 10, 10, 15},
    {15, 15, 20, 0},
    "green",
    {"00ff00", "000a00"},
    {1, 3, 0, 0});

// Halsted to Loop
Railway orangeLineCTA = Railway(
    {Checkpoint(41.84678, -87.648088), Checkpoint(41.85817, -87.627117), Checkpoint(41.875689, -87.626019), Checkpoint(41.876955, -87.626044), Checkpoint(41.885921, -87.626137), Checkpoint(41.885840, -87.633990), Checkpoint(41.876835, -87.633710), Checkpoint(41.8767992, -87.6255196)},
    {12, 7, 1, 10, 10, 10, 10},
    {12, 0, 40, 8},
    "orange",
    {"ff8000", "0a0500"},
    {3, 7, 1, 3});

// Sedgewick to Loop
Railway purpleLineCTA = Railway(
    {Checkpoint(41.9107586, -87.648068), Checkpoint(41.9103656, -87.6373962), Checkpoint(41.885840, -87.633990), Checkpoint(41.8770372, -87.6342823), Checkpoint(41.8767992, -87.6255196), Checkpoint(41.885921, -87.626137), Checkpoint(41.885840, -87.633990)},
    {5, 15, 10, 10, 10, 10},
    {20, 0, 40, 0},
    "purple",
    {"2000ff", "02000a"},
    {2, 6, 0, 0});

// Kedzie to Loop
Railway pinkLineCTA = Railway(
    {Checkpoint(41.853964, -87.705408), Checkpoint(41.854856, -87.6695341), Checkpoint(41.8849389, -87.6696133), Checkpoint(41.885840, -87.633990), Checkpoint(41.885921, -87.626137), Checkpoint(41.8767992, -87.6255196), Checkpoint(41.8770372, -87.6342823), Checkpoint(41.885840, -87.633990)},
    {7, 7, 6, 10, 10, 10, 10},
    {14, 0, 40, 6},
    "pink",
    {"ff8080", "0a0505"},
    {3, 7, 2, 3});

/// JFK/UMass to Harvard
Railway redLineMBTA = Railway{
    {Checkpoint(42.320414, -71.052139), Checkpoint(42.327649, -71.057760), Checkpoint(42.344627, -71.056986), Checkpoint(42.350559, -71.052613), Checkpoint(42.360982, -71.070116), Checkpoint(42.363490, -71.100487), Checkpoint(42.372535, -71.115947)},
    {5, 10, 5, 10, 10, 10},
    {0, 50, 0, 0},
    "red",
    {"ff0000", "0a0000"},
    {0, 0, 0, 0}};

// Wood Island to Bowdoin
Railway blueLineMBTA = Railway{
    {Checkpoint(42.379551, -71.023236), Checkpoint(42.360008, -71.047623), Checkpoint(42.359257, -71.059615), Checkpoint(42.361149, -71.062128)},
    {20, 10, 10},
    {0, 40, 0, 0},
    "blue",
    {"0000ff", "00000a"},
    {0, 0, 0, 0}};

// Roxbury Crossing to Wellington
Railway orangeLineMBTA = Railway{
    {Checkpoint(42.331520, -71.095285), Checkpoint(42.347474, -71.076055), Checkpoint(42.346967, -71.064553), Checkpoint(42.357606, -71.057324), Checkpoint(42.377410, -71.075941), Checkpoint(42.403125, -71.077024)},
    {10, 5, 10, 10, 10},
    {0, 45, 0, 0},
    "orange",
    {"ff8000", "0a0500"},
    {0, 0, 0, 0}};

// Kenmore to Union Square
Railway greenLine1MBTA = Railway{
    {Checkpoint(42.348957, -71.095080), Checkpoint(42.349616, -71.079112), Checkpoint(42.351835, -71.070836), Checkpoint(42.352342, -71.064498), Checkpoint(42.362111, -71.057983), Checkpoint(42.366666, -71.061263), Checkpoint(42.365633, -71.064124), Checkpoint(42.377506, -71.095170)},
    {10, 10, 10, 10, 10, 10, 10},
    {0, 70, 0, 0},
    "green",
    {"00ff00", "000a00"},
    {0, 0, 0, 0}};

// Longwood Medical Center to Back Bay(merges with green1)
Railway greenLine2MBTA = Railway{
    {Checkpoint(42.335878, -71.100229), Checkpoint(42.349616, -71.079112)},
    {15},
    {0, 15, 0, 0},
    "green",
    {"00ff00", "000a00"},
    {0, 0, 0, 0}};

std::vector<City> cities;
std::vector<Railway> ctaRailways, mbtaRailways;

std::vector<int> addressArr;  // i2c addresses in numerical order
std::vector<int> sequenceArr; // organizes i2c addresses from addressArr to correspond with railway vector

int brownLineCTAAdr = 0;
int greenLineCTAAdr[2] = {0, 0};

const BleUuid serviceUuid("a73ba101-8192-4a51-b42d-ae9cd14b14a5");
const BleUuid rxUuid("6E400002-B5A3-F393-E0A9-E50E24DCCA9E");
const BleUuid txUuid("6E400003-B5A3-F393-E0A9-E50E24DCCA9E");

BleCharacteristic txCharacteristic("tx", BleCharacteristicProperty::NOTIFY, txUuid, serviceUuid);
BleCharacteristic rxCharacteristic("rx", BleCharacteristicProperty::WRITE_WO_RSP, rxUuid, serviceUuid, onDataReceived, NULL);

MQTT client("lab.thewcl.com", 1883, callback);

HttpClient http;
http_header_t headers[] = {
    {"Accept", "/*/"},
    {NULL, NULL}};
http_request_t request;
http_response_t response;

JsonParserStatic<10000, 1000> parser;

String SSID = "";
String password = "";

Adafruit_AlphaNum4 d1 = Adafruit_AlphaNum4();
Adafruit_AlphaNum4 d2 = Adafruit_AlphaNum4();
Adafruit_AlphaNum4 d3 = Adafruit_AlphaNum4();
Adafruit_AlphaNum4 d4 = Adafruit_AlphaNum4();
Adafruit_AlphaNum4 d5 = Adafruit_AlphaNum4();
Adafruit_AlphaNum4 d6 = Adafruit_AlphaNum4();
Adafruit_AlphaNum4 d7 = Adafruit_AlphaNum4();

Adafruit_VL6180X vl = Adafruit_VL6180X();

bool userInput = false;

int cityIndex = -1;
int cityIndexBuffer;

uint64_t lastTime;

void setup()
{
    Serial.begin(9600);

    // BLE setup
    BLE.on();
    BLE.addCharacteristic(txCharacteristic);
    BLE.addCharacteristic(rxCharacteristic);
    BleAdvertisingData data;
    data.appendServiceUUID(serviceUuid);
    BLE.advertise(&data);

    Wire.setClock(400000);
    Wire.begin();

    vl.begin();

    request.hostname = "trek.thewcl.com";
    request.port = 80;

    // sets checkpoint indexes for the point adjacent to three segments, only necessary for CTA
    // the first parameter is the checkpoint that is reached first, the second parameter is the checkpoint at the end
    brownLineCTA.setLoopIndex(2, 6);
    orangeLineCTA.setLoopIndex(3, 7);
    purpleLineCTA.setLoopIndex(2, 6);
    pinkLineCTA.setLoopIndex(3, 7);

    ctaRailways = {brownLineCTA, blueLineCTA, redLineCTA, greenLineCTA, orangeLineCTA, pinkLineCTA, purpleLineCTA};

    // greenLine1MBTA and greenLine2MBTA must be in adjacent in the vector
    mbtaRailways = {redLineMBTA, greenLine1MBTA, greenLine2MBTA, blueLineMBTA, orangeLineMBTA};

    // there needs to be the same number of rail lines and slaves expected when configuring through the app

    // TESTING
    // for testing purposes, the number of slaves for the CTA is set to 1
    // for actual development this needs to be set back to 7
    cities = {City(ctaRailways, "cta", 1), City(mbtaRailways, "mbta", 5)};
    // END TESTING

    d1.begin(0x70);
    d2.begin(0x71);
    d3.begin(0x72);
    d4.begin(0x73);
    d5.begin(0x74);
    d6.begin(0x75);
    d7.begin(0x76);

    // flashes slave code to every address
    for (int i = 0x08; i <= 0x69; i++)
    {
        flashProg(slaveCode, sizeof(slaveCode), i);
    }

    // TESTING
    // used for prototyping purposes, configures settings without need for app
    // works when ONE slave is connected and brownLineCTA is at index 0 of ctaRailways
    // shows the CTA brown/purple line and also all other trains in the loop
    delay(500);
    cityIndex = 0;
    sequenceArr = std::vector<int>(cities[cityIndex].railways.size() * 2, 0);
    addressArr = std::vector<int>(cities[cityIndex].slaveCountExpected, 0);
    randomizeAddress();
    sequenceArr[1] = addressArr[0];
    brownLineCTAAdr = addressArr[0];
    userInput = true;
    WiFi.setCredentials("WCL", "atmega328");
    WiFi.on();
    WiFi.connect();
    Particle.connect();
    // END TESTING

    new Thread("proximity", proximityThread, NULL, OS_THREAD_PRIORITY_DEFAULT, 1024);
    lastTime = System.millis();
}

void loop()
{
    delay(500);
    if (WiFi.hasCredentials() && userInput)
    {
        // re-flashes slave code to all slave addresses
        if (System.millis() - lastTime > UPDATE_INTERVAL)
        {
            for (int i : addressArr)
            {
                flashProg(slaveCode, sizeof(slaveCode), i);
            }
            lastTime = Time.now();
        }

        // MQTT reconnect if disconnected
        if (client.isConnected())
        {
            client.subscribe("loop-tracks/twitter");
            client.loop();
        }
        else
        {
            client.connect("sparkclient");
        }

        // dislay text on 14-segment displays
        if(cityIndex == 0){
            alphaDisplay(d1, "OHRE");
            alphaDisplay(d2, "HWRD");
            alphaDisplay(d3, "KDZI");
            alphaDisplay(d4, "PLSK");
            alphaDisplay(d5, "KDZI");
            alphaDisplay(d6, "HLST");
            alphaDisplay(d7, "CRMK");
        }

        for (int i : sequenceArr)
        {
            Serial.printf("%i, ", i);
        }
        Serial.println();

        cityIndexBuffer = cityIndex;
        for (unsigned int x = 0; x < cities[cityIndexBuffer].railways.size(); x++)
        {
            // gets data from WCL server
            request.path = "/loop-tracks/" + String(cities[cityIndexBuffer].name.c_str()) + "?lines=" + String(cities[cityIndexBuffer].railways[x].name.c_str());
            http.get(request, response, headers);

            Serial.println("parsing");
            parser.clear();
            parser.addString(response.body);
            if (!parser.parse())
            {
                Serial.println("parsing failed");
                return;
            }

            int trainIndex = 0;
            Railway currentRailway = cities[cityIndexBuffer].railways[x];

            // loop through each train, loop breaks when all trains have been parsed
            while (true)
            {
                if (parseTrain(trainIndex++, currentRailway))
                {
                    break;
                }
            }

            sendData(x, currentRailway);
            delay(1000);
        }

        Serial.println();
    }
}

void proximityThread(void *param)
{
    while (true)
    {
        Wire.lock();

        // rainbow led on when close proximity
        uint8_t range = vl.readRange();
        if (range <= PROXIMITY_THRESHOLD)
        {
            lightshow(1000);
        }

        Wire.unlock();
        // delay(100);
    }
}

void sendData(int railwayVectorIndex, Railway currentRailway)
{
    Wire.lock();

    // outputs train data to slaves
    for (int i = 0; i < 4; i++)
    {
        int adr;

        // sets the address of the slave to send to for the current rail block
        if (cities[cityIndexBuffer].name == "cta" && (i == 2 || currentRailway.name == purpleLineCTA.name))
        {
            adr = brownLineCTAAdr;
        }
        else if (cities[cityIndexBuffer].name == "cta" && i == 3)
        {
            if (currentRailway.name == orangeLineCTA.name)
            {
                adr = greenLineCTAAdr[0];
            }
            else
            {
                adr = greenLineCTAAdr[1];
            }
        }
        else
        {
            adr = sequenceArr[railwayVectorIndex * 2 + i];
        }

        // sends train color data to slave in preparation for the next set of train data
        Wire.beginTransmission(adr);
        Wire.write(currentRailway.colors[0].c_str());
        Wire.write(currentRailway.colors[1].c_str());
        Wire.endTransmission();

        Wire.beginTransmission(adr);

        // padding for cta
        if (cities[cityIndexBuffer].name == "cta")
        {
            // padding for loop
            if (i == 2)
            {
                // pads green line sending to loop
                if (currentRailway.name == greenLineCTA.name)
                {
                    for (unsigned int x = 0; x < brownLineCTA.outputs[0].size() + (brownLineCTA.outputs[2].size() / 2); x++)
                    {
                        Wire.write('0');
                    }
                }

                // prevents brown/purple line from getting overriden
                else if (currentRailway.name == brownLineCTA.name || currentRailway.name == purpleLineCTA.name)
                {
                    for (unsigned int x = 0; x < brownLineCTA.outputs[0].size(); x++)
                    {
                        Wire.write((char)currentRailway.outputs[0][x] + '0');
                    }
                }

                // pads every other line sending to loop
                else
                {
                    for (unsigned int x = 0; x < brownLineCTA.outputs[0].size(); x++)
                    {
                        Wire.write('0');
                    }
                }
            }

            // pad orange line sending to green
            if (i == 3 && currentRailway.name == orangeLineCTA.name)
            {
                for (unsigned int x = 0; x < greenLineCTA.outputs[0].size() - orangeLineCTA.outputs[3].size(); x++)
                {
                    Wire.write('0');
                }
            }

            // pad pink line sending to green
            else if (i == 3 && currentRailway.name == pinkLineCTA.name)
            {
                for (unsigned int x = 0; x < greenLineCTA.outputs[0].size() - pinkLineCTA.outputs[3].size(); x++)
                {
                    Wire.write('0');
                }
            }
        }

        // sends train data to slave
        Serial.printf("%s rail block %i: ", currentRailway.name.c_str(), i);
        for (unsigned int x = 0; x < currentRailway.outputs[i].size(); x++)
        {
            Wire.write((char)currentRailway.outputs[i][x] + '0');
            Serial.print(currentRailway.outputs[i][x]);
        }
        Serial.println();
        Wire.endTransmission(true);
    }
    for (int i = 0; i < 4; i++)
    {
        for (unsigned int x = 0; x < currentRailway.outputs[x].size(); x++)
        {
            currentRailway.outputs[i][x] = 0;
        }
    }
    Serial.println();

    Wire.unlock();
}
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

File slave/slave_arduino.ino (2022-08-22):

// #include <ArduinoUniqueID.h>
#include <Adafruit_NeoPixel.h>
#include <Arduino.h>
#include <avr/wdt.h>
#include "src/Wire/src/Wire.h" // local copy of Wire.h so we can override the buffer size limit
#include <EEPROM.h>

#define MAX_PIXELS 100
#define CHALLENGE_LEN 25 // 24 + 1 for null terminator
#define BLINK LED_BUILTIN
#define UPDATE A1

volatile int address;
volatile bool verifyAddress = true;
volatile int requestMode = 0;
volatile bool blink = false;
volatile bool clear = false;
volatile bool refresh = false;
volatile bool reboot = false;
volatile uint32_t headColor;
volatile uint32_t tailColor;

char challenge[CHALLENGE_LEN];

Adafruit_NeoPixel strip(MAX_PIXELS, 2, NEO_GRB + NEO_KHZ800);

void rainbow(uint8_t wait);
uint32_t Wheel(byte WheelPos);
void(* resetFunc) (void) = 0;

void setup()
{
    Serial.begin(115200);

    // initialize randomness w/ analog read of pin A0
    // instead of Unique ID, as it doesn't work for some reason
    randomSeed(analogRead(0));

    // adds the rest of the random digits to the device id
    for (size_t i = 0; i < CHALLENGE_LEN; i++)
    {
        challenge[i] = (char)random('0', '9');
    }

    challenge[CHALLENGE_LEN - 1] = '\0';

    address = random(0x08, 0x69);

    // address 48 is for VL6180
    while (address == 0x29 || address == 0x30)
    {
        address = random(0x08, 0x69);
    }
    if(EEPROM.read(0) == 255){
        EEPROM.write(0, address);
    }else{
        address = EEPROM.read(0);
    }

    // address = 0x08;

    Wire.setClock(400000);
    Wire.begin(address);
    Wire.onReceive(dataReceived);
    Wire.onRequest(dataRequest);

    strip.begin();
    strip.setBrightness(255);
    strip.clear();
    strip.show();
    pinMode(6, INPUT);
}

void loop()
{
    if (clear)
    {
        strip.clear();
        strip.show();
        clear = false;
    }

    if (blink)
    {
        rainbow(5);
    }else{
        strip.setBrightness(255);
    }

    if (!verifyAddress)
    {
        Serial.print(F("randomize address: "));
        Serial.println(address);
        address = random(0x08, 0x69);

        while (address == 0x29 || address == 0x30)
        {
            address = random(0x08, 0x69);
        }
        EEPROM.write(0, address);

        Serial.println(address);

        Wire.end();
        Wire.setClock(400000);
        Wire.begin(address);
        Wire.onReceive(dataReceived);
        Wire.onRequest(dataRequest);
        requestMode = 0;
        verifyAddress = true;
    }

    if (refresh)
    {
        refresh = false;
        strip.show();
    }
}

void dataReceived(int count)
{
    int size = Wire.available();
    char inputBuffer[size];
    int counter = 0;
    Serial.print("Data recieved: ");
    while (Wire.available() > 0)
    {
        char c = Wire.read();
        inputBuffer[counter] = c;
        counter++;
    }
    inputBuffer[counter] = '\0';
    Serial.println(inputBuffer);

    if (size == 1)
    {
        if (inputBuffer[0] == '1')
        {
            requestMode = 1;
            return;
        }
        else if (inputBuffer[0] == '2')
        {
            requestMode = 2;
            return;
        }
        else if (inputBuffer[0] == '3')
        {
            blink = true;
            return;
        }
        else if (inputBuffer[0] == '4')
        {
            blink = false;
            clear = true;
            return;
        }
        else if (inputBuffer[0] == '9') // Tell the device to reboot
        {
            pinMode(6, OUTPUT);
        }
    }
    else if (size == 24)
    {
        for (int i = 0; i < 24; i++)
        {
            if (challenge[i] != inputBuffer[i])
            {
                verifyAddress = false;
                return;
            }
        }
    }
    else if (size == 12)
    {
        char headBuffer[7];
        char tailBuffer[7];
        for (int i = 0; i < 6; i++)
        {
            headBuffer[i] = inputBuffer[i];
            tailBuffer[i] = inputBuffer[i + 6];
        }
        headBuffer[6] = '\0';
        tailBuffer[6] = '\0';
        headColor = strtoul(headBuffer, NULL, 16);
        tailColor = strtoul(tailBuffer, NULL, 16);
        return;
    }
    else
    {
        for (int i = 0; i < size + 1; i++)
        {
            if (strip.getPixelColor(i) == headColor || strip.getPixelColor(i) == tailColor)
            {
                strip.setPixelColor(i, 0);
            }
        }
        for (int i = 0; i < size; i++)
        {
            if (inputBuffer[i] == '1')
            {
                strip.setPixelColor(i - 1, tailColor);
                strip.setPixelColor(i, tailColor);
                strip.setPixelColor(i + 1, headColor);
            }
            else if (inputBuffer[i] == '5')
            {
                strip.setPixelColor(i - 1, headColor);
                strip.setPixelColor(i, tailColor);
                strip.setPixelColor(i + 1, tailColor);
            }
        }
        refresh = true;
        return;
    }
}

void dataRequest()
{
    // Serial.println("request received");
    switch (requestMode)
    {
        case 1:
        {
            // Serial.println("request mode 1");
            Wire.write(challenge);
            break;
        }
        case 2:
        {
            // Serial.println("request mode 2");
            // Serial.println((unsigned long)UniqueID);
            if (verifyAddress)
            {
                Wire.write("pass");
            }
            else
            {
                Wire.write("fail");
            }
            break;
        }
        default:
        {
            Wire.write(0);
            break;
        }
    }
}

void rainbow(uint8_t wait)
{
    strip.setBrightness(32);
    uint16_t i, j;

    for (j = 0; j < 256; j++)
    {
        for (i = 0; i < strip.numPixels(); i++)
        {
            strip.setPixelColor(i, Wheel((i + j) & 255));
        }
        strip.show();
        delay(wait);
    }
}

// Input a value 0 to 255 to get a color value.
// The colours are a transition r - g - b - back to r.
uint32_t Wheel(byte WheelPos)
{
    if (WheelPos < 85)
    {
        return strip.Color(WheelPos * 3, 255 - WheelPos * 3, 0);
    }
    else if (WheelPos < 170)
    {
        WheelPos -= 85;
        return strip.Color(255 - WheelPos * 3, 0, WheelPos * 3);
    }
    else
    {
        WheelPos -= 170;
        return strip.Color(0, WheelPos * 3, 255 - WheelPos * 3);
    }
}

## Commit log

2021-07-27 i2c address algorithm
2022-06-28 railway vectors
2022-07-05 end pixel fix
    [microcontroller board.kicad_pcb, microcontroller board.kicad_sch]
2022-07-06 straight stick
    [Adafruit NeoPixel 8 Stick v2.brd, Adafruit NeoPixel 8 Stick v2.sch, Adafruit NeoPixel 8 Stick.brd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]
2022-07-06 cleaner routing
    [Adafruit NeoPixel 8 Stick.kicad_pcb]
2022-07-06 4 pin fix
    [Adafruit NeoPixel 8 Stick v2.brd, Adafruit NeoPixel 8 Stick v2.sch, Adafruit NeoPixel 8 Stick.brd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]
2022-07-06 90 connectors
    [Adafruit NeoPixel 8 Stick.kicad_pcb, Adafruit NeoPixel 8 Stick.kicad_sch]
2022-07-06 45 connector
    [Adafruit NeoPixel 8 Stick.kicad_pcb, Adafruit NeoPixel 8 Stick.kicad_sch]
2022-07-06 4 way intersection
    [Adafruit NeoPixel 8 Stick.kicad_pcb, Adafruit NeoPixel 8 Stick.kicad_sch]
2022-07-07 6 pin
    [Adafruit NeoPixel 8 Stick.kicad_pcb, Adafruit NeoPixel 8 Stick.kicad_sch]
2022-07-08 track split
2022-07-11 added beginnings of t junction
    [Adafruit NeoPixel 8 Stick.kicad_pcb, Adafruit NeoPixel 8 Stick.kicad_sch]
2022-07-12 changes to T intersection
    [Adafruit NeoPixel 8 Stick.kicad_pcb]
2022-07-12 made microcontroller mount
    [Adafruit NeoPixel 8 Stick.kicad_pcb, Adafruit NeoPixel 8 Stick.kicad_sch]
2022-07-12 added argon mount
    [Adafruit NeoPixel 8 Stick.kicad_pcb, Adafruit NeoPixel 8 Stick.kicad_sch]
2022-07-12 finished power supply
    [Adafruit NeoPixel 8 Stick.kicad_pcb, Adafruit NeoPixel 8 Stick.kicad_sch]
2022-07-12 left t junction update
    [Adafruit NeoPixel 8 Stick.kicad_pcb, Adafruit NeoPixel 8 Stick.kicad_sch]
2022-07-12 added straight t intersection
    [Adafruit NeoPixel 8 Stick.kicad_pcb, Adafruit NeoPixel 8 Stick.kicad_sch]
2022-07-15 i2c randomize fix
2022-07-15 t intersections
    [45 degree left.STEP, 45 degree right.STEP, 90 degree left.STEP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]
2022-07-15 half size straight stick
    [Adafruit NeoPixel 8 Stick.kicad_pcb, Adafruit NeoPixel 8 Stick.kicad_sch, T straight right.STEP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]
2022-07-18 mount edges
    [Adafruit NeoPixel 8 Stick.kicad_pcb, argon mount.STEP, microcontroller mount.STEP]
2022-07-18 proximity sensor
2022-07-18 arduino slave
2022-07-20 porting to arduino
2022-07-20 arduino port
2022-07-20 device id
2022-07-21 t straight fix
    [Adafruit NeoPixel 8 Stick.kicad_pcb, Adafruit NeoPixel 8 Stick.kicad_sch]
2022-07-21 argon mount
    [Adafruit NeoPixel 8 Stick.kicad_pcb, Adafruit NeoPixel 8 Stick.kicad_sch, Adafruit VL6180 Time of Flight Sensor.kicad_pcb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]
2022-07-22 segment display pcb
    [AlphaNumeric Featherwing rev A.kicad_pcb, AlphaNumeric Featherwing rev A.kicad_sch]
2022-07-22 redo microcontroller board
    [ATMEGA328P-PU.step, Adafruit NeoPixel 8 Stick.kicad_pcb, Adafruit NeoPixel 8 Stick.kicad_sch]
2022-07-28 changed pcbs
    [Adafruit NeoPixel 8 Stick.kicad_pcb, Adafruit NeoPixel 8 Stick.kicad_sch]
2022-07-28 edited boards
    [Adafruit NeoPixel 8 Stick.kicad_pcb, Adafruit NeoPixel 8 Stick.kicad_sch]
2022-08-05 updated some pcbs
    [Adafruit NeoPixel 8 Stick.kicad_pcb, Adafruit NeoPixel 8 Stick.kicad_sch]
2022-08-05 clean up boards + generate some gerber files
    [Adafruit NeoPixel 8 Stick-B_Cu.gbr, Adafruit NeoPixel 8 Stick-B_Mask.gbr, Adafruit NeoPixel 8 Stick-B_Paste.gbr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]
2022-08-08 rm vias over pads
    [Adafruit NeoPixel 8 Stick-B_Cu.gbr, Adafruit NeoPixel 8 Stick-B_Mask.gbr, Adafruit NeoPixel 8 Stick-B_Paste.gbr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]
2022-08-08 move vias off pads
    [Adafruit NeoPixel 8 Stick.kicad_pcb, AlphaNumeric Featherwing rev A.kicad_pcb]
2022-08-08 arduino reboot
2022-08-08 renamed project files
    [14_segment_display.kicad_pcb, 14_segment_display.kicad_sch, 45deg_left_turn.kicad_pcb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]
2022-08-09 update timer
2022-08-09 atmega reset
    [microcontroller_th.kicad_pcb, microcontroller_th.kicad_sch]
2022-08-09 Squashed commit of the following:
    commit 3b9e75c34fcf5fbcdf9d23706f6c16b9b6f41cae
    Author: Arjun-Saini <69866165+Arjun-Saini@users.noreply.github.com>
    Date: Tue Aug 9 10:25:40 2022 -0500
    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
    [microcontroller_th.kicad_pcb, microcontroller_th.kicad_sch]
2022-08-10 default i2c address
2022-08-11 sensor 0x30
2022-08-11 thread fix
2022-08-16 argon pcb fix
    [argon_mount.kicad_pcb, argon_mount.kicad_sch]
2022-08-17 t-intersection pcbs
    [t_intersection_from_left.kicad_pcb, t_intersection_from_left.kicad_sch, t_intersection_from_right.kicad_pcb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]
2022-08-18 power pcb fix
    [power_mount.kicad_pcb]
2022-08-19 blocked intersection
    [blocked_intersection.kicad_pcb, blocked_intersection.kicad_sch, t_intersection_offshoot.kicad_pcb]
2022-08-22 lightshow power reduction
2022-08-24 mount fix + offshoot flip
    [14 segment display.STEP, argon mount.STEP, argon_mount.kicad_pcb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]
